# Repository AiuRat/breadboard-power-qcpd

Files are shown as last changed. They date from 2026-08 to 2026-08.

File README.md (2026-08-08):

<p align="center">
  <b>Русский</b> | <a href="README.en.md">English</a> | <a href="README.de.md">Deutsch</a>
</p>

# Breadboard Power QC/PD

Модуль комбинированного питания для беспаечных макетных плат с поддержкой протоколов быстрой зарядки **USB Power Delivery (PD)** и **Quick Charge (QC)**.

<p align="center">
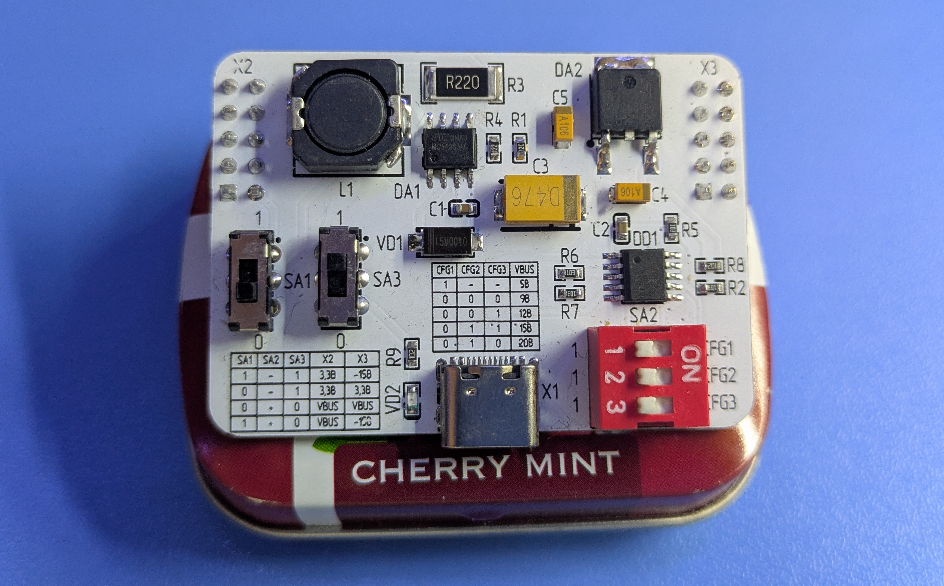
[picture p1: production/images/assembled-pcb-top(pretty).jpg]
Breadboard Power QC/PD Assembled Board
  
</p>

---

## 1. Описание проекта

**Breadboard Power QC/PD** — это компактное, универсальное устройство, призванное решить проблему питания прототипов на беспаечных макетных платах. Традиционные лабораторные блоки питания громоздки и требуют ручной настройки, а дешевые китайские модули питания макеток ограничены жесткими рамками 5 В и 3,3 В при малом токе.

Данный проект объединяет современные технологии быстрой зарядки по протоколу **USB Type-C (QC/PD)**, высокую точность линейных стабилизаторов и широкие возможности импульсных DC-DC преобразователей. Модуль подключается напрямую в боковые шины макетной платы и предоставляет инженеру независимые каналы питания для цифровой логики, микроконтроллеров и аналоговых микросхем (двуполярное питание ±15 В).

---

## 2. Основные технические характеристики

* **Входной интерфейс:** USB Type-C (с поддержкой PD 3.0 / QC 3.0)
* **Интерфейс подключения:** Двухрядные штыревые разъемы с шагом 2,54 мм (под стандартные шины макетных плат)
* **Доступные каналы и напряжения:**
  * Силовой регулируемый канал (`VBUS`): **5 В / 9 В / 12 В / 15 В / 20 В** (определяется триггером)
  * Канал питания логики (`3.3Vout`): **+3,3 В** (малошумящий линейный LDO-стабилизатор)
  * Канал отрицательного плеча (`-15out`): **-15 В** (импульсный инвертирующий преобразователь)

---

## 3. Схемотехника и архитектура устройства

Полная принципиальная электрическая схема модуля:

<p align="center">
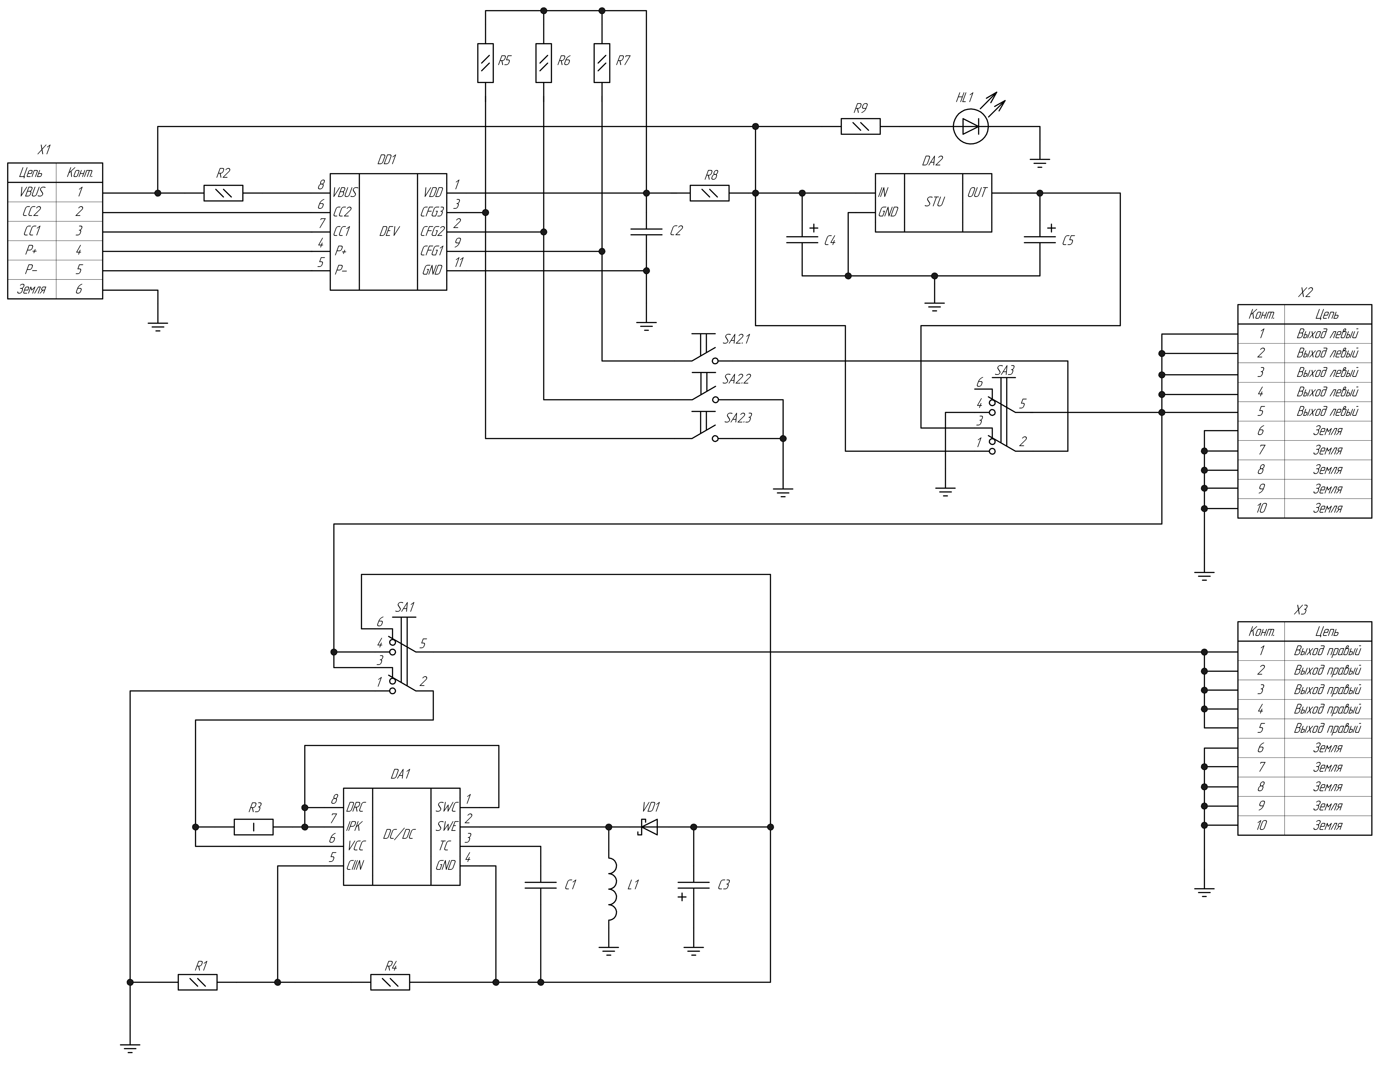
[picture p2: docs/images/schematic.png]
Принципиальная схема Breadboard Power QC/PD
  
</p>

### Архитектура модуля состоит из трех ключевых узлов:
1. **Узел триггера быстрой зарядки:** Выполнен на специализированной микросхеме **CH224K**. Она ведет переговоры с внешним источником питания (адаптером) через линии `CC1/CC2` и «вытягивает» нужное напряжение на шину `VBUS`. Конфигурация задается DIP-переключателем `SA2`.
2. **Линейный LDO-стабилизатор (+3,3 В):** Построен на базе микросхемы **LD1086DT33TR** (в корпусе TO-252) с входными и выходными фильтрующими конденсаторами емкостью 10 мкФ.
3. **Импульсный инвертор (-15 В):** Выполнен по инвертирующей схеме на ШИМ-контроллере **MC34063AG-S08-R** без внешнего ключа. Частота работы генератора задается емкостью $C_1 = 2{,}2\text{ нФ}$ ($\approx 97{,}5\text{ кГц}$).

---

## 4. Конструкция и 3D-моделирование (Mechanical Design)

Для защиты электроники и удобства использования был спроектирован двухсоставной защитный пластиковый корпус в среде **КОМПАС-3D** (соединение деталей по системе шип-паз):

<p align="center">
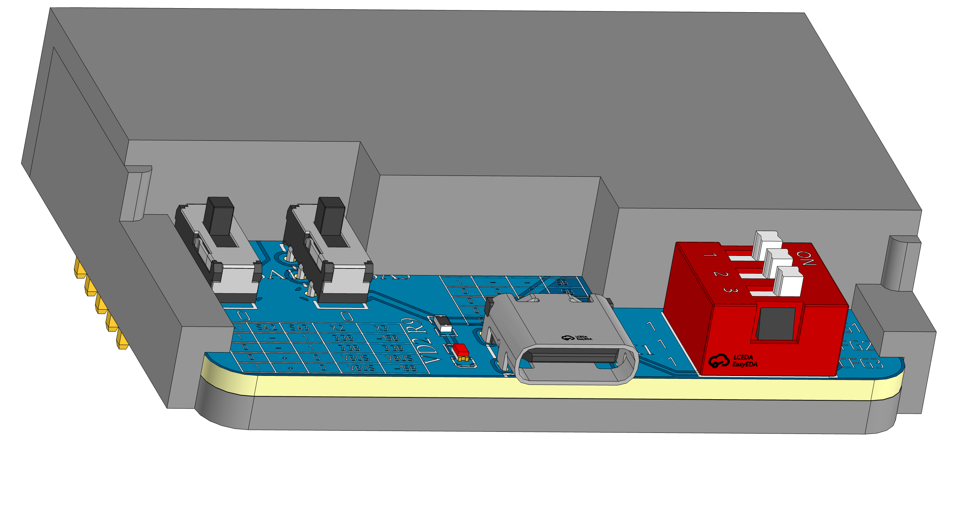
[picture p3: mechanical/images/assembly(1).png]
3D-модель корпуса - Вид 1
  
</p>

*Детали корпуса (крышка и подложка) оптимизированы под аддитивное производство методом FDM-печати на 3D-принтере (файлы `.stl` для печати находятся в папке [`mechanical/enclosure/`](mechanical/enclosure)).*

---

## 5. Лабораторные испытания и верификация (Hardware Verification)

Устройство было успешно спаяно и прошло тестирование:

<p align="center">
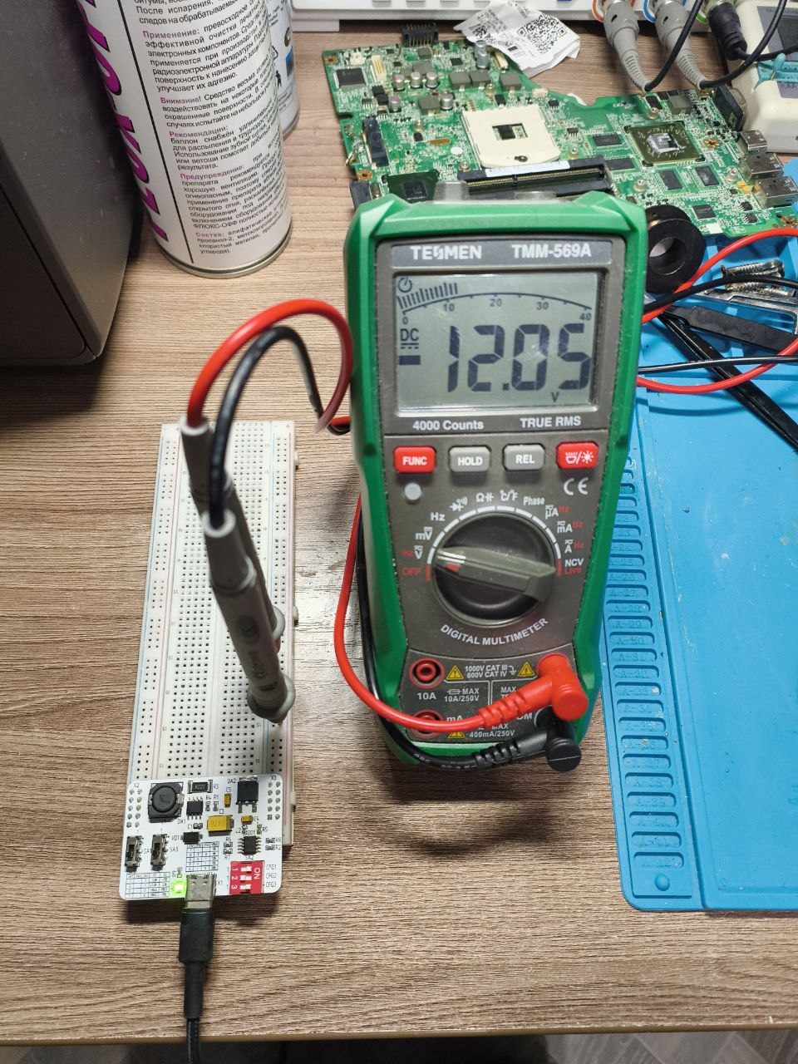
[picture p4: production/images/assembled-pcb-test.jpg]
Физическое тестирование собранного макета
  
</p>

В ходе верификации с помощью цифрового осциллографа была подтверждена стабильность работы встроенного генератора инвертора и непрерывный режим работы силовой индуктивности:

<p align="center">
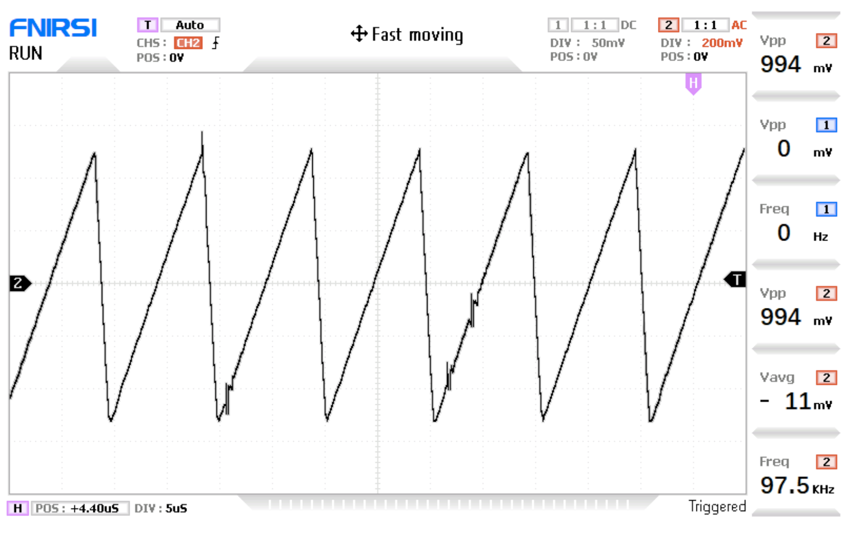
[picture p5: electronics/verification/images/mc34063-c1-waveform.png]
Осциллограмма C1
  
  &nbsp;&nbsp;&nbsp;&nbsp;
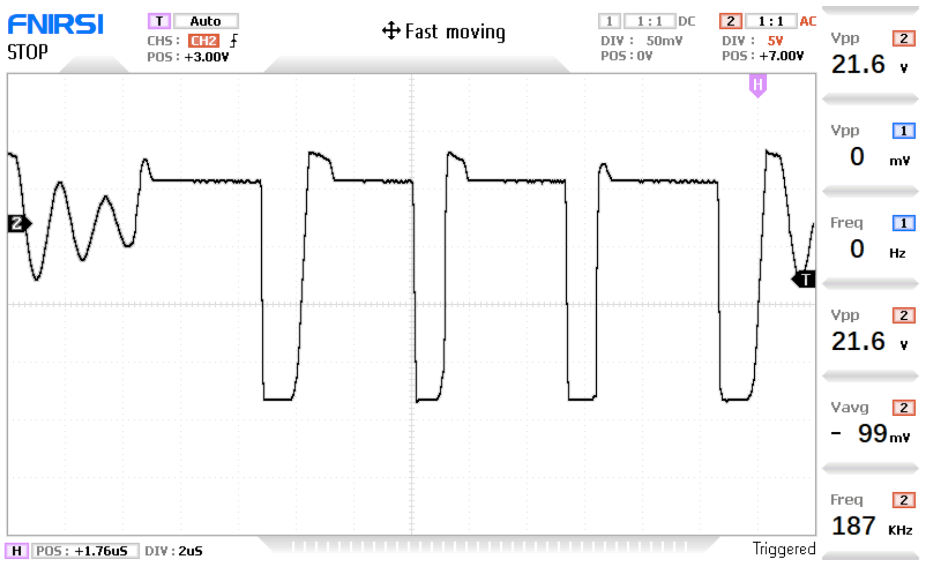
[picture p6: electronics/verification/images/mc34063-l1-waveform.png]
Осциллограмма L1
  
</p>

* **Осциллограмма C1 (слева):** Подтверждает рабочую частоту переключения преобразователя 97,5 кГц (в пределах допустимой нормы в 100 кГц).
* **Осциллограмма L1 (справа):** Подтверждает правильный выбор индуктивности 220 мкГн, обеспечивающий стабильный непрерывный ток дросселя без ухода в режим разрывных токов.

---

## 6. Таблицы конфигурации переключателей

### 6.1. Выбор входного напряжения QC/PD (Переключатель `SA2`)

| `CFG1` | `CFG2` | `CFG3` | Выходное напряжение `VBUS` |
| :---: | :---: | :---: | :---: |
| 1 | — | — | **5 В** |
| 0 | 0 | 0 | **9 В** |
| 0 | 0 | 1 | **12 В** |
| 0 | 1 | 1 | **15 В** |
| 0 | 1 | 0 | **20 В** |

*Примечание: «1» означает разомкнутое состояние переключателя (высокий уровень за счет подтяжки к VDD), «0» — замкнут на GND.*

### 6.2. Коммутация шин питания макетной платы (Переключатели `SA1`, `SA3`)

| Положение `SA1` | Положение `SA3` | Напряжение на левой шине `X2` | Напряжение на правой шине `X3` |
| :---: | :---: | :---: | :---: |
| 1 | 1 | +3,3 В | -15 В |
| 0 | 1 | +3,3 В | +3,3 В |
| 0 | 0 | `VBUS` (от триггера) | `VBUS` (от триггера) |
| 1 | 0 | `VBUS` (от триггера) | -15 В |

---

## 7. Навигация по проекту

Репозиторий имеет четкую модульную структуру. Перейдите в интересующий вас раздел по ссылкам ниже для ознакомления с исходными материалами:

* 📁 **[`/electronics`](electronics)** — Аппаратная часть проекта. Содержит исходные файлы схемы и платы в формате EasyEDA, а также подпапку **[`verification`](electronics/verification)** с подробными математическими расчетами обвязки преобразователя и осциллограммами тестов.
* 📁 **[`/mechanical`](mechanical)** — Механическая часть и корпус. Содержит исходные параметрические модели деталей корпуса в КОМПАС-3D (`.m3d`, `.a3d`) и готовые файлы для 3D-печати на FDM-принтере (`.stl`).
* 📁 **[`/production`](production)** — Файлы для самостоятельной сборки и заказа. Содержит архив Gerber-файлов для завода (`gerber.zip`), перечень элементов для закупки компонентов (`BOM.xlsx`) и чертежи в формате PDF.
* 📁 **[`/docs`](docs)** — Техническая документация. Содержит глубокое описание физики работы схемы устройства, таблицы истинности переключателей и подпапку **[`datasheets`](docs/datasheets)** с оригинальной документацией на используемые микросхемы.

---

## Лицензия

Copyright (c) 2026 Айрат Ялалетдинов

Этот исходный документ описывает открытое аппаратное обеспечение (Open Hardware) и распространяется под лицензией CERN-OHL-P v2. 
Вы можете распространять и изменять этот исходный документ, а также производить на его основе продукты в соответствии с 
условиями лицензии CERN-OHL-P v2 (https://cern.ch/cern-ohl).

Этот исходный документ распространяется БЕЗ КАКИХ-ЛИБО ЯВНЫХ ИЛИ ПОДРАЗУМЕВАЕМЫХ ГАРАНТИЙ, 
ВКЛЮЧАЯ ГАРАНТИИ ТОВАРНОЙ ПРИГОДНОСТИ, УДОВЛЕТВОРИТЕЛЬНОГО КАЧЕСТВА ИЛИ СООТВЕТСТВИЯ 
КОНКРЕТНЫМ ЦЕЛЯМ. Пожалуйста, ознакомьтесь с условиями CERN-OHL-P v2 для получения подробной информации.

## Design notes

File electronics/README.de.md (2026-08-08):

<p align="center">
  <a href="README.md">Русский</a> | <a href="README.en.md">English</a> | <b>Deutsch</b>
</p>

# Hardware-Entwicklung (Electronics)

Hier befinden sich alle Materialien im Zusammenhang mit dem Entwurf, der Berechnung und dem Layout der Leiterplatte des kombinierten Stromversorgungsmoduls.

## Verzeichnisstruktur

* **[`easyeda`](/electronics/easyeda)** — Original-Projektdateien im `.json`-Format für den Import in EasyEDA CAD (Schaltplan und Leiterplatten-Topologie).
* **[`verification`](/electronics/verification)** — Ordner mit detaillierten technischen Berechnungen der Bauteildimensionierung, Formeln und Oszillogrammen der physischen Tests des fertigen Prototyps.
* **[`images`](/electronics/images)** — grafische Materialien des Projekts (Screenshots des Schaltplans, der Routing-Ebenen und der 3D-Modelle der Leiterplatte).

---

## Schaltplan des Geräts

Vollständiger elektrischer Schaltplan des Moduls, erstellt in EasyEDA:

<p align="center">
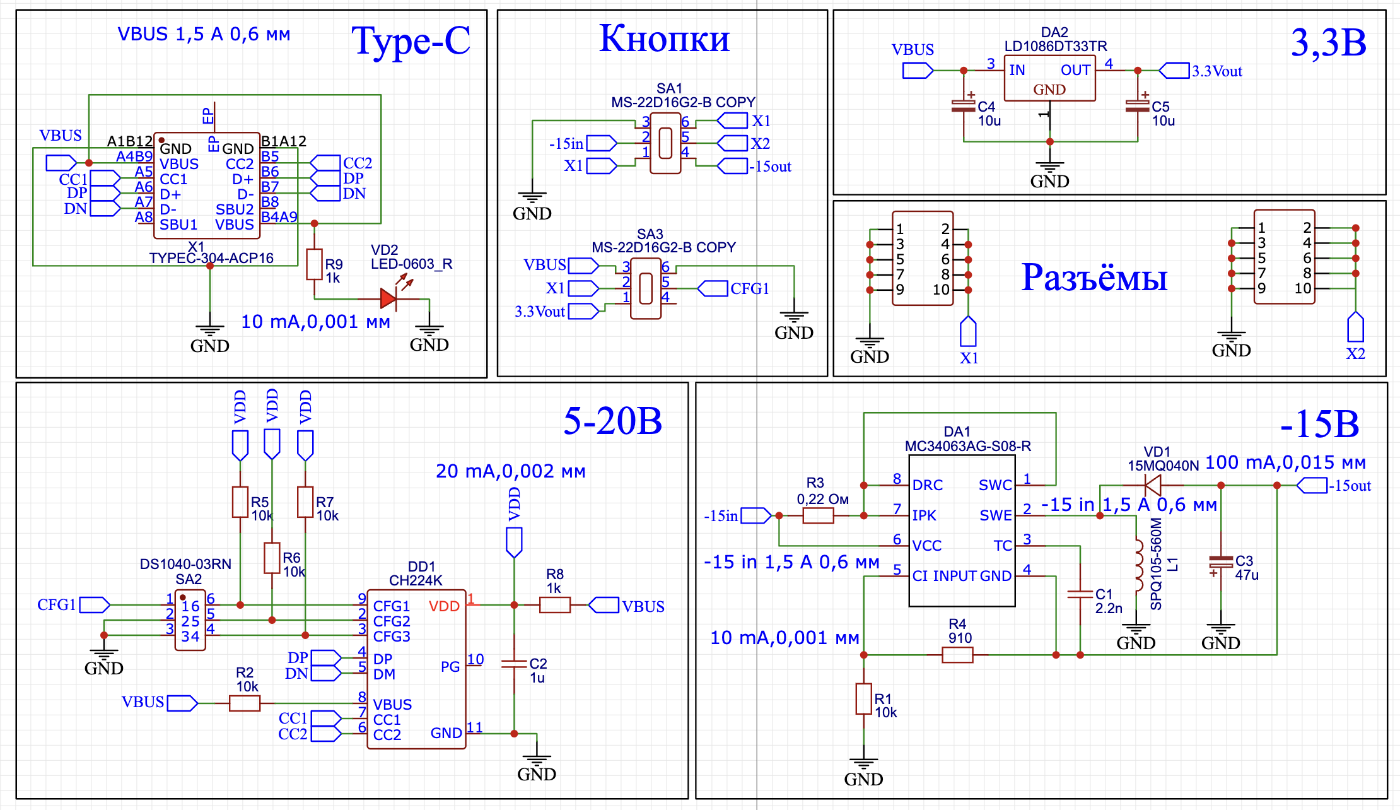
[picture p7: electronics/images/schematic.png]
Schaltplan des Geräts
  
</p>

---

## Leiterplatten-Topologie (PCB)

Zweilagige Leiterplatte mit optimiertem Routing der Leistungsbahnen und Masseflächen (ohne Bauteildarstellung):

<p align="center">
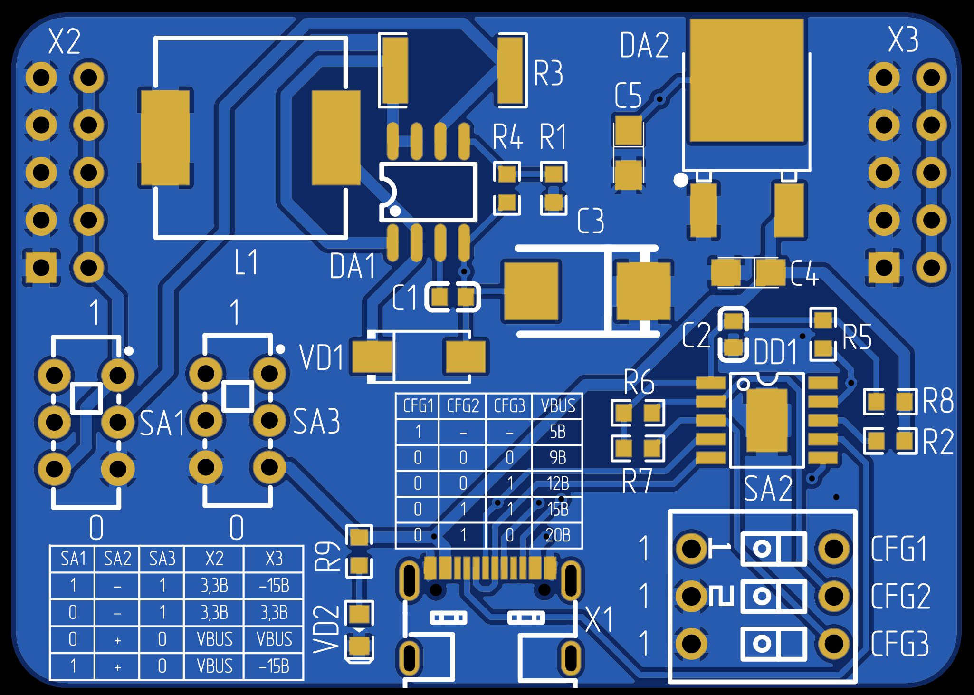
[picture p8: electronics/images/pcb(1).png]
Leiterplatten-Topologie - Draufsicht
  
  &nbsp;&nbsp;&nbsp;&nbsp;
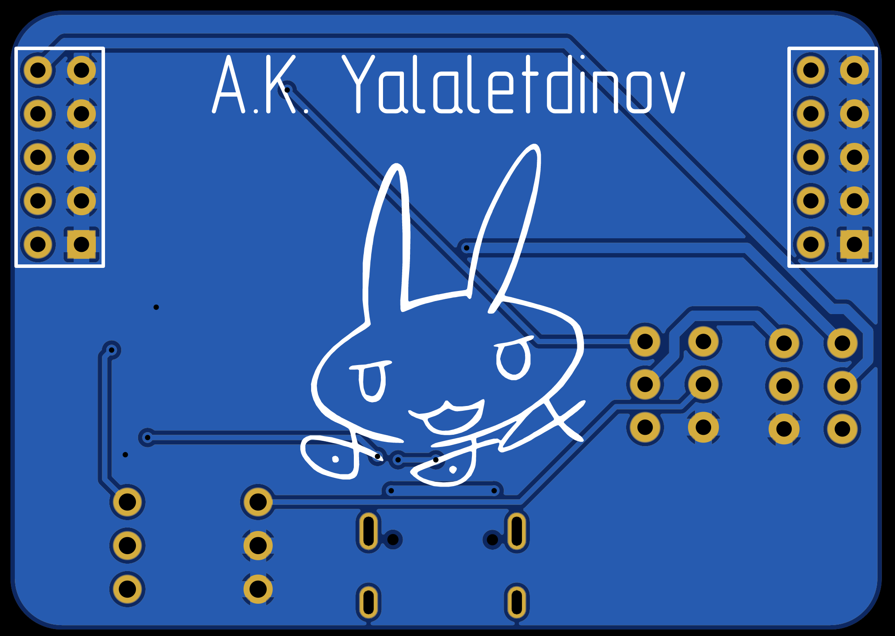
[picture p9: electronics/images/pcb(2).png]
Leiterplatten-Topologie - Unteransicht
  
</p>

---

## 3D-Visualisierung (3D Render)

Realistische 3D-Renderings der Leiterplatte mit bestückten Bauteilen:

<p align="center">
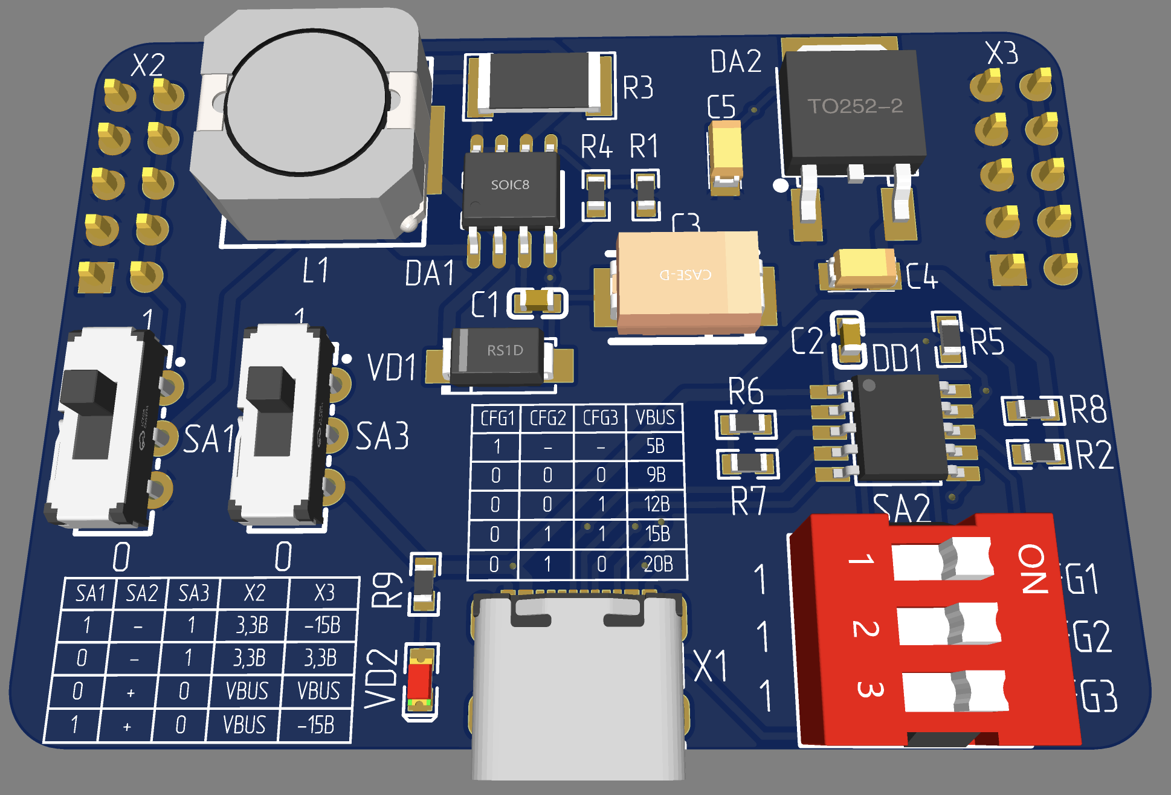
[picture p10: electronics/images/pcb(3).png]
3D-Modell der Leiterplatte - Ansicht 1
  
  &nbsp;&nbsp;&nbsp;&nbsp;
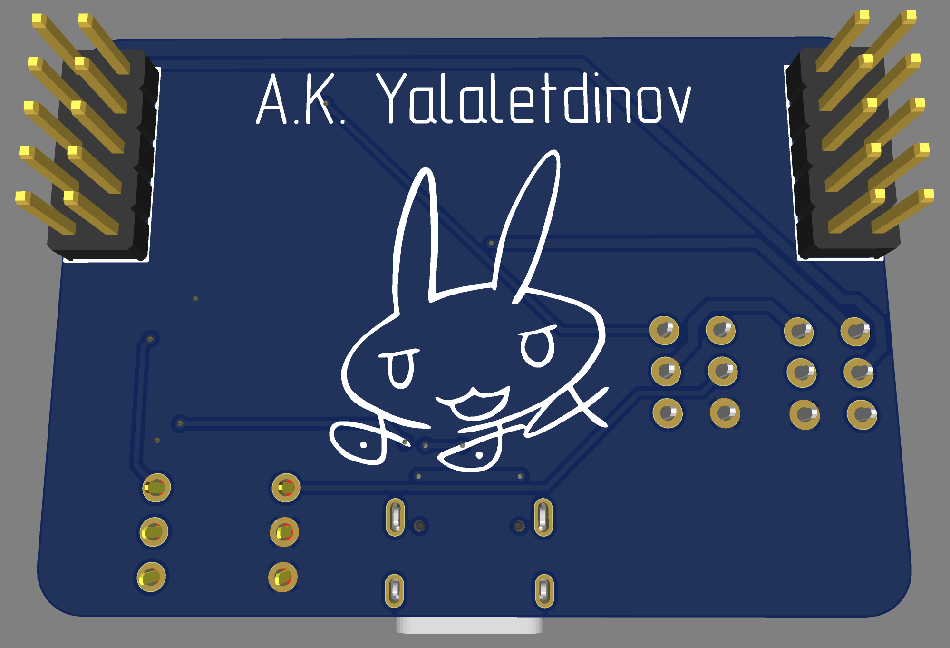
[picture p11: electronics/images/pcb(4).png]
3D-Modell der Leiterplatte - Ansicht 2
  
</p>

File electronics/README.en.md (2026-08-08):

<p align="center">
  <a href="README.md">Русский</a> | <b>English</b> | <a href="README.de.md">Deutsch</a>
</p>

# Hardware Development (Electronics)

This folder contains all materials related to the design, calculation, and routing of the combined power module PCB.

## Directory Structure

* **[`easyeda`](/electronics/easyeda)** — source project files in `.json` format for import into EasyEDA CAD (schematic and PCB topology).
* **[`verification`](/electronics/verification)** — folder with detailed engineering calculations for component values, formulas, and waveforms from physical testing of the finished prototype.
* **[`images`](/electronics/images)** — graphical assets of the project (screenshots of the schematic, routing layers, and 3D PCB models).

---

## Device Schematic Diagram

Full electrical schematic diagram of the module, designed in EasyEDA:

<p align="center">
  Device schematic diagram
</p>

---

## PCB Topology

Two-layer printed circuit board with optimized routing of power traces and ground planes (components not shown):

<p align="center">
  PCB topology - top view
  &nbsp;&nbsp;&nbsp;&nbsp;
  PCB topology - bottom view
</p>

---

## 3D Visualization (3D Render)

Realistic 3D renders of the printed circuit board with installed components:

<p align="center">
  3D PCB model - angle 1
  &nbsp;&nbsp;&nbsp;&nbsp;
  3D PCB model - angle 2
</p>

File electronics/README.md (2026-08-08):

<p align="center">
  <b>Русский</b> | <a href="README.en.md">English</a> | <a href="README.de.md">Deutsch</a>
</p>

# Разработка аппаратной части (Electronics)

Здесь содержатся все материалы, связанные с проектированием, расчетом и трассировкой печатной платы модуля комбинированного питания.

## Структура директории

* **[`easyeda`](/electronics/easyeda)** — исходные файлы проекта в формате `.json` для импорта в САПР EasyEDA (принципиальная схема и топология печатной платы).
* **[`verification`](/electronics/verification)** — папка с подробными инженерными расчетами обвязки микросхем, формулами и осциллограммами физических испытаний готового макета.
* **[`images`](/electronics/images)** — графические материалы проекта (скриншоты схемы, слоев трассировки и 3D-модели платы).

---

## Принципиальная схема устройства

Полная принципиальная электрическая схема модуля, выполненная в EasyEDA:

<p align="center">
  Принципиальная схема устройства
</p>

---

## Топология печатной платы (PCB)

Двухслойная печатная плата с оптимизированной разводкой силовых дорожек и полигонов заземления (без отображения компонентов):

<p align="center">
  Топология платы - вид сверху
  &nbsp;&nbsp;&nbsp;&nbsp;
  Топология платы - вид снизу
</p>

---

## Трехмерная визуализация (3D Render)

Реалистичные 3D-рендеры печатной платы с установленной элементной базой:

<p align="center">
  3D модель платы - ракурс 1
  &nbsp;&nbsp;&nbsp;&nbsp;
  3D модель платы - ракурс 2
</p>

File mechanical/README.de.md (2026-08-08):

<p align="center">
  <a href="README.md">Русский</a> | <a href="README.en.md">English</a> | <b>Deutsch</b>
</p>

# Mechanische Konstruktion (Mechanical)

Hier befinden sich alle Materialien im Zusammenhang mit der Konstruktion, der 3D-Gehäusemodellierung und der Erstellung der Konstruktionsdokumentation.

## Verzeichnisstruktur

* **[`drawings/`](/mechanical/drawings)** — Ordner mit Konstruktionszeichnungen und Spezifikationen im Originalformat von KOMPAS-3D (`.cdw`).
* **[`enclosure/`](/mechanical/enclosure)** — parametrische 3D-Modelle der Gehäuseteile (`.m3d`), fertige 3D-Druckdateien (`.stl`) und das 3D-Modell des montierten Geräts (`.a3d`).
* **[`images/`](/mechanical/images)** — grafische Materialien (hochwertige Renders von 3D-Modellen und Screenshots von Zeichnungen).

---

## 3D-Gehäusebaugruppe (3D Enclosure Assembly)

Renderings des in KOMPAS-3D entworfenen 3D-Gehäusemodells (Abdeckung und Bodenplatte) zusammen mit der Leiterplatte:

<p align="center">
  Gehäusebaugruppe - Ansicht 1
  &nbsp;&nbsp;&nbsp;&nbsp;
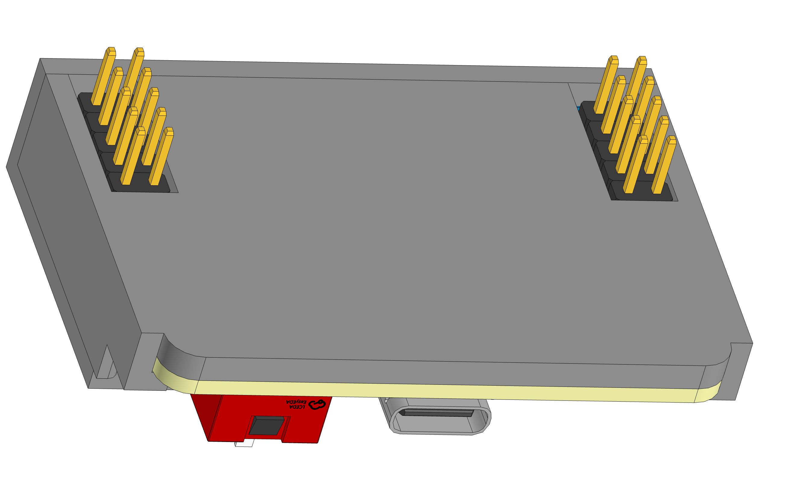
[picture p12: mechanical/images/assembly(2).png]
Gehäusebaugruppe - Ansicht 2
  
</p>

---

## Konstruktionszeichnungen des Produkts (Drawings)

Nachfolgend sind die wichtigsten Blätter der grafischen Dokumentation des Projekts dargestellt, die nach ESKD-Standards erstellt wurden:

### 1. Elektrischer Schaltplan (Schematic)
<p align="center">
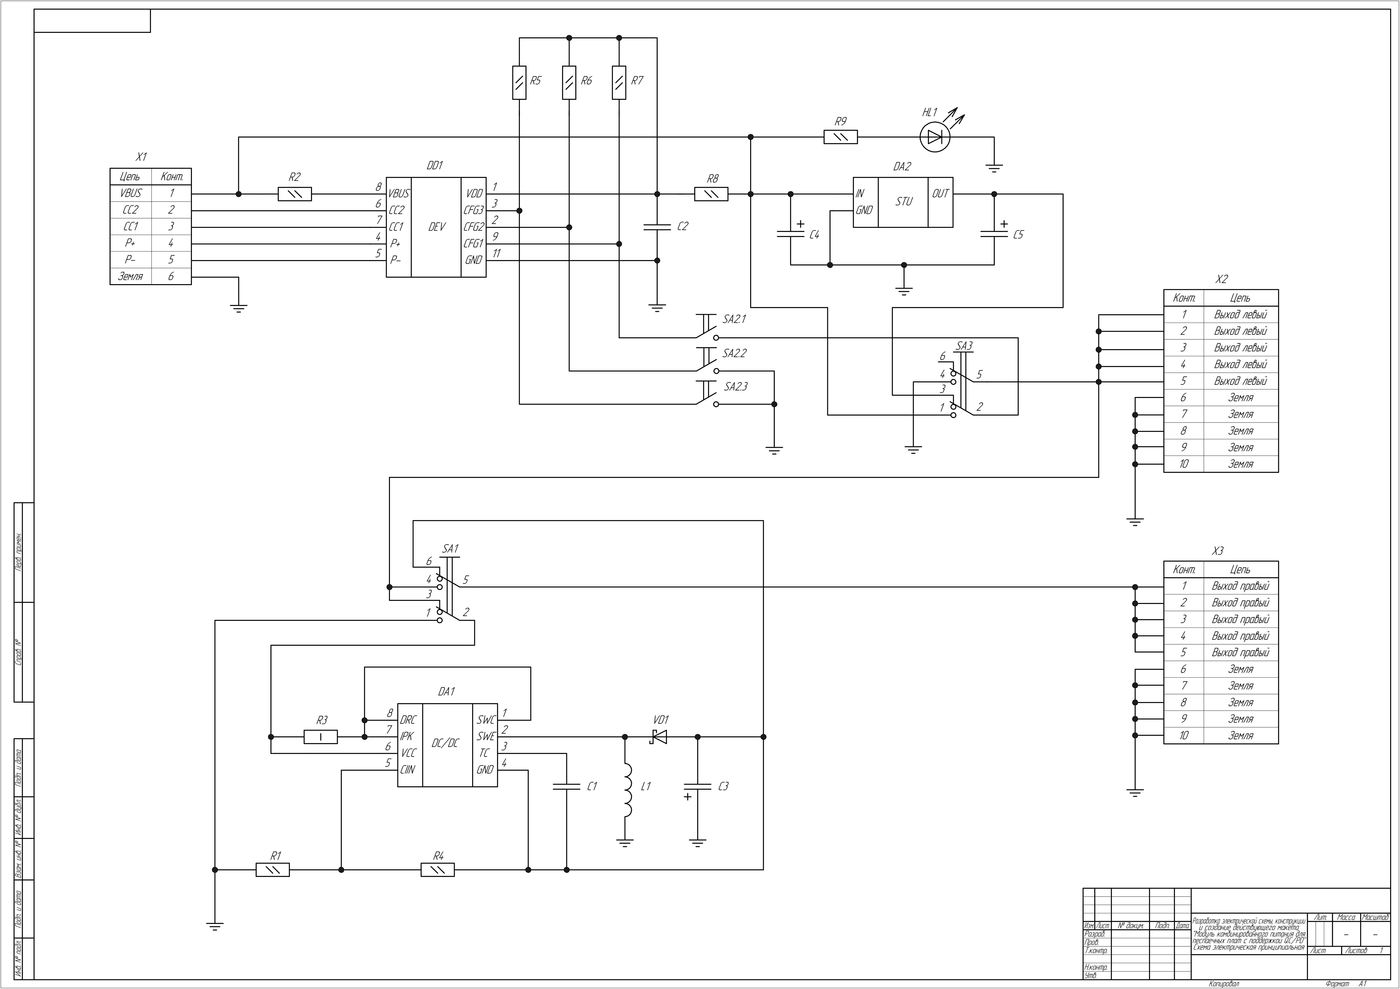
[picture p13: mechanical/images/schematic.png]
Elektrischer Schaltplan
  
</p>

### 2. Baugruppenzeichnung des Geräts (Assembly Drawing)
<p align="center">
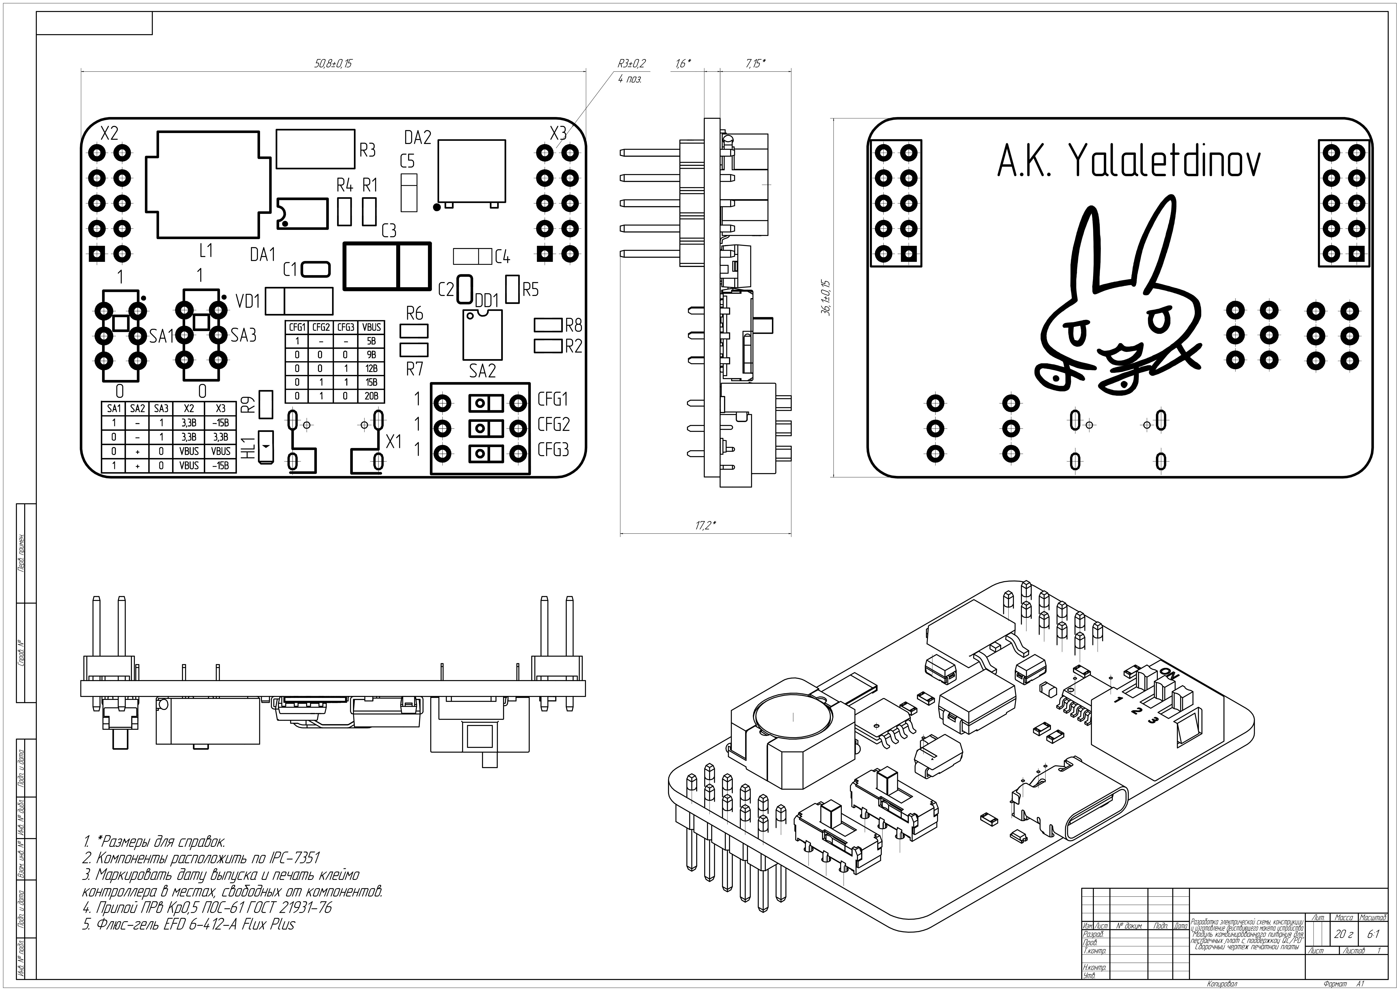
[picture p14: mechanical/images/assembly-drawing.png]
Baugruppenzeichnung des Geräts
  
</p>

### 3. Leiterplattenzeichnung (PCB Drawing)
<p align="center">
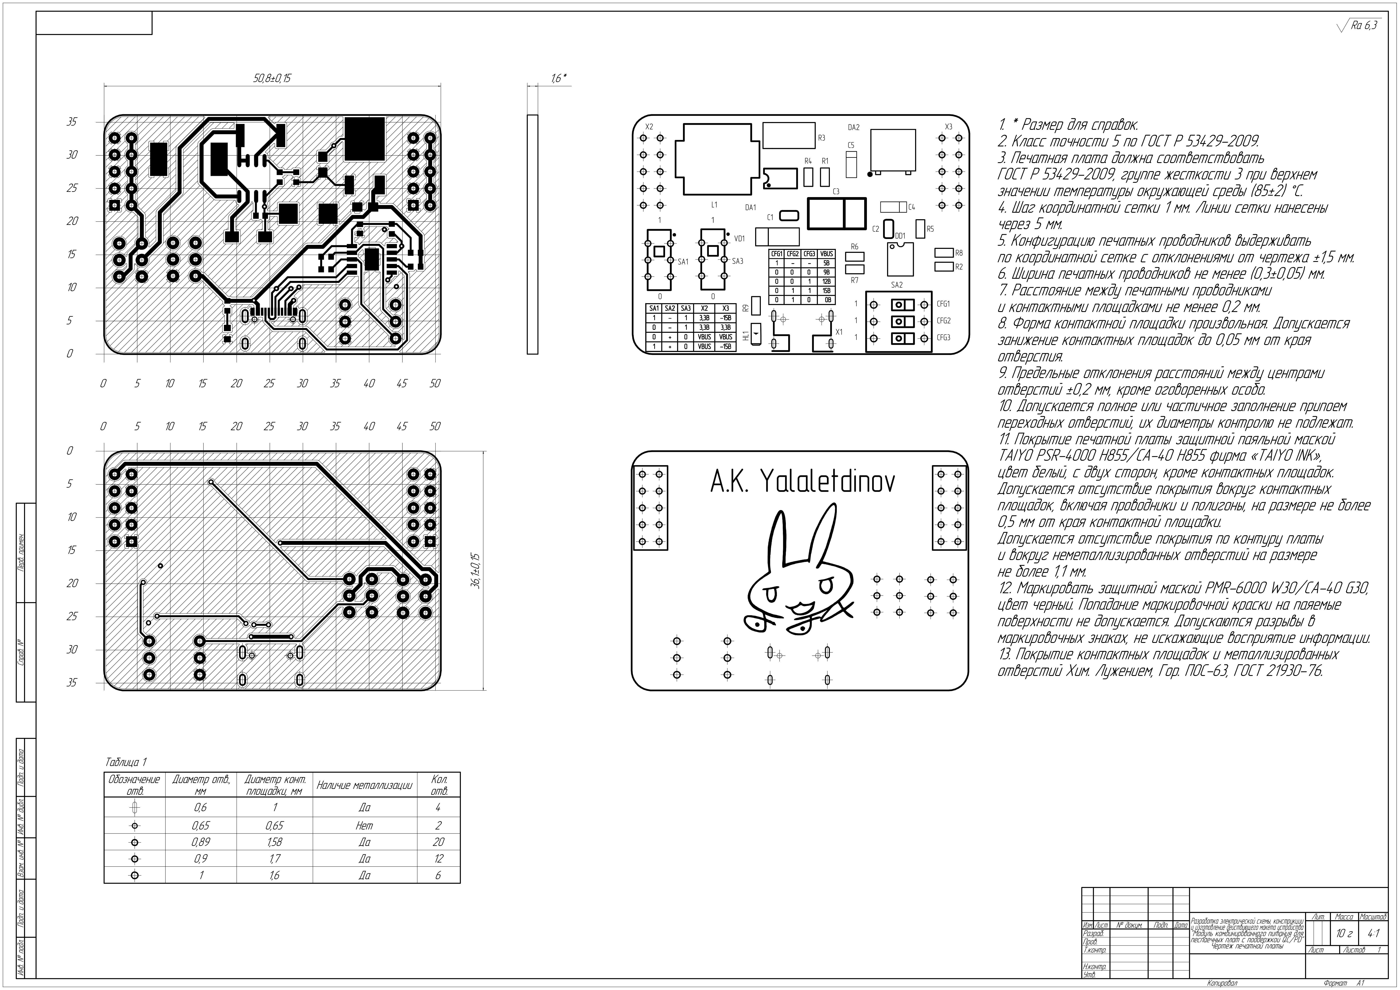
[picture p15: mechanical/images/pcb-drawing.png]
Leiterplattenzeichnung
  
</p>

### 4. Gesamtansichtszeichnung des Produkts (General View)
<p align="center">
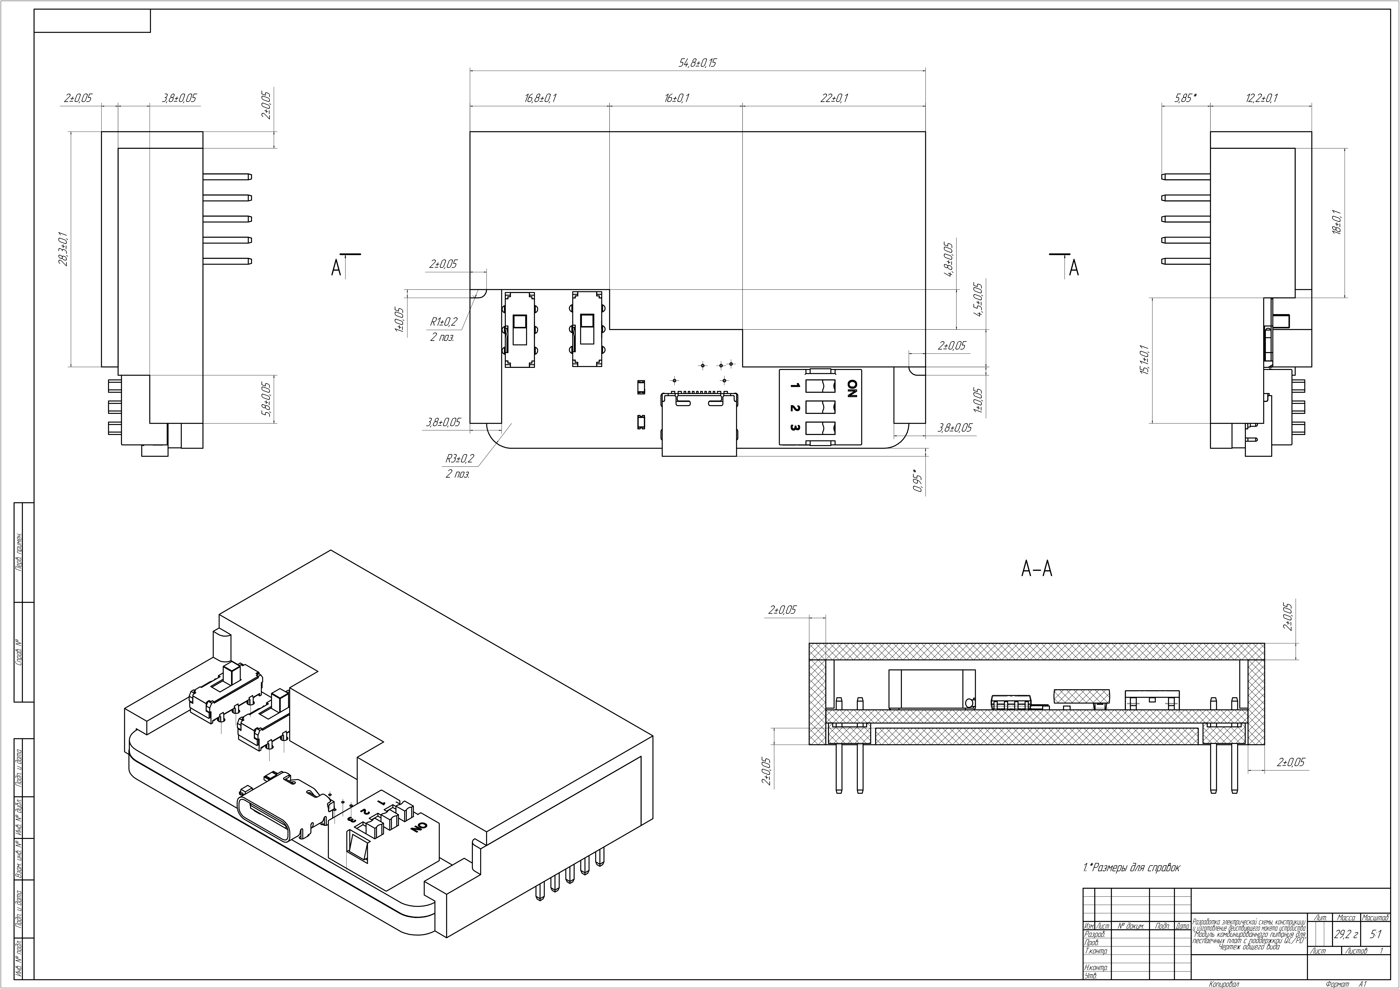
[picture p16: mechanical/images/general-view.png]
Gesamtansichtszeichnung des Produkts
  
</p>

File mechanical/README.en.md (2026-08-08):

<p align="center">
  <a href="README.md">Русский</a> | <b>English</b> | <a href="README.de.md">Deutsch</a>
</p>

# Mechanical Design (Mechanical)

This folder contains all materials related to structural development, 3D enclosure modeling, and engineering documentation release.

## Directory Structure

* **[`drawings/`](/mechanical/drawings)** — folder with engineering drawings and specifications in the native KOMPAS-3D format (`.cdw`).
* **[`enclosure/`](/mechanical/enclosure)** — parametric 3D models of enclosure parts (`.m3d`), ready-to-print 3D printing files (`.stl`), and the 3D model of the assembled device (`.a3d`).
* **[`images/`](/mechanical/images)** — graphical assets (high-quality 3D model renders and drawing screenshots).

---

## 3D Enclosure Assembly

Renders of the 3D enclosure model (top cover and bottom plate) assembled with the printed circuit board, designed in KOMPAS-3D:

<p align="center">
  Enclosure Assembly - Angle 1
  &nbsp;&nbsp;&nbsp;&nbsp;
  Enclosure Assembly - Angle 2
</p>

---

## Engineering Drawings

Below are the main sheets of the project's graphical documentation, prepared in accordance with ESKD standards:

### 1. Electrical Schematic Diagram (Schematic)
<p align="center">
  Electrical Schematic Diagram
</p>

### 2. Device Assembly Drawing (Assembly Drawing)
<p align="center">
  Device Assembly Drawing
</p>

### 3. Printed Circuit Board Drawing (PCB Drawing)
<p align="center">
  Printed Circuit Board Drawing
</p>

### 4. General View Drawing (General View)
<p align="center">
  General View Drawing
</p>

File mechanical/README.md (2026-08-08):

<p align="center">
  <b>Русский</b> | <a href="README.en.md">English</a> | <a href="README.de.md">Deutsch</a>
</p>

# Проектирование механической части (Mechanical)

Здесь содержатся все материалы, связанные с разработкой конструкции, 3D-моделированием корпуса и выпуском конструкторской документации.

## Структура директории

* **[`drawings/`](/mechanical/drawings)** — папка с конструкторскими чертежами и спецификациями в исходном формате КОМПАС-3D (`.cdw`).
* **[`enclosure/`](/mechanical/enclosure)** — параметрические 3D-модели деталей корпуса по частям (`.m3d`), готовые файлы для 3D-печати (`.stl`) и 3D-модель устройства в сборе (`.a3d`).
* **[`images/`](/mechanical/images)** — графические материалы (высококачественные рендеры 3D-моделей и скриншоты чертежей).

---

## Трехмерная сборка корпуса (3D Enclosure Assembly)

Рендеры 3D-модели корпуса (крышка и подложка) в сборе с печатной платой, спроектированные в среде КОМПАС-3D:

<p align="center">
  Сборка корпуса - Ракурс 1
  &nbsp;&nbsp;&nbsp;&nbsp;
  Сборка корпуса - Ракурс 2
</p>

---

## Конструкторские чертежи изделия (Drawings)

Ниже представлены основные листы графической документации проекта, выполненные по стандартам ЕСКД:

### 1. Схема электрическая принципиальная (Schematic)
<p align="center">
  Схема электрическая принципиальная
</p>

### 2. Сборочный чертеж устройства (Assembly Drawing)
<p align="center">
  Сборочный чертеж устройства
</p>

### 3. Чертеж печатной платы (PCB Drawing)
<p align="center">
  Чертеж печатной платы
</p>

### 4. Чертеж общего вида изделия (General View)
<p align="center">
  Чертеж общего вида изделия
</p>

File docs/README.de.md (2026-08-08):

<p align="center">
  <a href="README.md">Русский</a> | <a href="README.en.md">English</a> | <b>Deutsch</b>
</p>

# Funktionsbeschreibung des Schaltungsentwurfs des kombinierten Stromversorgungsmoduls

Dieses Dokument enthält eine detaillierte technische Beschreibung der Funktionsweise des elektrischen Schaltplans für das "Kombinierte Stromversorgungsmodul für lötfreie Steckplatinen (Breadboards) mit QC/PD-Unterstützung".

<p align="center">
  Schaltplan des Geräts
</p>

## 1. Verwendungszweck und Gesamtarchitektur

Das Gerät ist dafür ausgelegt, lötfreie Steckplatinen während des Prototyping und des Debugging von elektronischen Geräten mit einer stabilen mehrkanaligen Stromversorgung zu versorgen. Das Modul wandelt die Eingangsspannung eines externen Ladegeräts oder einer externen Powerbank, die Schnellladeprotokolle unterstützen, in einen Satz stabilisierter Spannungen um:
* **Schnellladekanal (VBUS):** einstellbare Spannung von $5\text{ V}$, $9\text{ V}$, $12\text{ V}$, $15\text{ V}$ oder $20\text{ V}$ (wird durch die Trigger-Anforderung bestimmt).
* **Niederspannungskanal für Logikversorgung:** feste Spannung von $+3{,}3\text{ V}$.
* **Negativer Spannungskanal (symmetrische Spannungsversorgung):** feste Spannung von $-15\text{ V}$.

---

## 2. Funktionsweise der einzelnen Baugruppen

Der elektrische Schaltplan des Geräts besteht aus fünf miteinander verbundenen Hauptblöcken:

### 2.1. USB Type-C Eingangsstufe
Der Betrieb des Moduls beginnt mit dem Anlegen einer externen Stromversorgung an den Anschluss **`X1`** (Typ *TYPEC-304-ACP16*). 
* Die Kontakte `A4/B9` und `B4/A9` sind zu einer gemeinsamen Eingangsstromschiene **`VBUS`** zusammengefasst.
* Die Kontakte `A1/B12` und `B1/A12` sind mit der Systemmasse **`GND`** verbunden.
* Die Kanalkonfigurationskontakte `CC1` und `CC2` sind zum Schnelllade-Trigger herausgeführt, um die Aushandlung mit der Stromquelle durchzuführen.
* Die LED **`VD2`** (mit dem Strombegrenzungswiderstand `R10` von $1\text{ k}\Omega$) dient zur visuellen Anzeige der Eingangsspannung auf der `VBUS`-Schiene.

### 2.2. Aushandlungseinheit für Schnellladeprotokolle (QC/PD)
Das Schlüsselelement für die Kommunikation mit dem Netzteil ist der Trigger-IC **`DD1`** vom Typ **`CH224K`**. Er unterstützt hardwareseitig die Protokolle USB Power Delivery (PD3.0/2.0), Quick Charge (QC3.0/2.0) und andere.
* Die Signalleitungen `DP` (D+) und `DM` (D-) sowie die Konfigurationsleitungen `CC1` und `CC2` sind direkt mit den entsprechenden Pins von `DD1` verbunden.
* Die Betriebslogik des Triggers wird durch den Zustand seiner Konfigurationseingänge `CFG1`, `CFG2` und `CFG3` bestimmt. Diese Eingänge werden durch die Widerstände `R5`, `R6`, `R7` von $10\text{ k}\Omega$ auf die interne Versorgungsschiene `VDD` hochgezogen (pull-up) und über einen dreistufigen DIP-Schalter **`SA2`** (*DS1040-03RN*) gesteuert.
* Durch Schließen der entsprechenden Kontakte des Schalters `SA2` gegen Masse (`GND`) stellt der Benutzer manuell den gewünschten Spannungspegel (von $5\text{ V}$ bis $20\text{ V}$) ein.

### 2.3. LDO-Linearreglerstufe ($+3{,}3\text{ V}$)
Für die zuverlässige Stromversorgung von Mikrocontrollern und digitalen Sensoren wird ein leistungsstarker Linearregler mit geringem Spannungsabfall (LDO) **`DA2`** vom Typ **`LD1086DT33TR`** (im TO-252-Gehäuse) verwendet.
* Die Spannung von der Schiene `VBUS` wird an den Eingang `IN` des Reglers angelegt. Obwohl `VBUS` bis auf $20\text{ V}$ ansteigen kann, hält der IC `LD1086` Eingangsspannungen von bis zu $30\text{ V}$ sicher stand.
* Zur Unterdrückung hochfrequenter Störungen und transienter Vorgänge sind am Ein- und Ausgang des Reglers Keramikkondensatoren **`C4`** ($10\text{ }\mu\text{F}$) und **`C5`** ($10\text{ }\mu\text{F}$) installiert.

### 2.4. Invertierender DC-DC-Wandler ($-15\text{ V}$)
Die negative Spannung wird von einem invertierenden Schaltregler auf Basis des klassischen PWM-Controllers **`DA1`** vom Typ **`MC34063AG-S08-R`** erzeugt.
* **Prinzip der Invertierung:** Wenn der interne Leistungstransistor des ICs eingeschaltet ist, fließt Strom durch die Drossel **`L1`** ($220\text{ }\mu\text{H}$) und speichert Energie in ihrem Magnetfeld. Die Schottky-Diode **`VD1`** (*15MQ040N*) ist in diesem Moment gesperrt. Wenn der Transistor sperrt, versucht die Induktivität, die Stromrichtung beizubehalten, die Selbstinduktions-EMK kehrt ihre Polarität um, die Diode `VD1` leitet und überträgt negative Ladung auf den Ausgangskondensator **`C3`** ($47\text{ }\mu\text{H}$).
* **Überstromschutz:** Der Widerstand **`R3`** ($0{,}22\text{ }\Omega$) zwischen den Pins `DRC/IPK` und dem Stromeingang legt die Schwelle für die Begrenzung des Drossel-Spitzenstroms fest, um eine Beschädigung des Wandlers bei einem Kurzschluss zu verhindern.
* **Rückkopplung (Feedback):** Die Ausgangsspannung wird von einem Komparator über einen Teiler aus den Widerständen **`R4`** ($910\text{ }\Omega$), **`R5`** ($750\text{ }\Omega$) und **`R1`** ($10\text{ k}\Omega$) überwacht, der an den Rückkopplungseingang `CIIN` (Pin 5) angeschlossen ist. Der Kondensator **`C1`** ($2{,}2\text{ nF}$) bestimmt die Schaltfrequenz des PWM-Generators ($\approx 97{,}5\text{ kHz}$).

### 2.5. Ausgangsschaltschema und Ausgangsanschlüsse
Die Verteilung der Spannungen auf die linke und rechte Schiene der Steckplatine erfolgt über zwei unabhängige Schiebeschalter **`SA1`** und **`SA3`** (*MS-22D16G2-B*).
* Die Schalter leiten die physischen Ausgänge der Schienen `3.3Vout`, `VBUS` und `-15out` an die Ausgangsstiftleisten **`X2`** und **`X3`** (Typ *DS1021-2x5*) weiter.
* Die Anschlüsse haben ein Rastermaß von $2{,}54\text{ mm}$ und befinden sich an den Rändern der Leiterplatte, so dass das Modul direkt in die seitlichen Standard-Stromschienen einer lötfreien Steckplatine gesteckt werden kann.

---

## 3. Konfigurationstabellen der Schalter

### 3.1. Auswahl der QC/PD-Eingangsspannung (Schalter `SA2`)

| `CFG1` | `CFG2` | `CFG3` | Ausgangsspannung `VBUS` |
| :---: | :---: | :---: | :---: |
| 1 | — | — | **5 V** |
| 0 | 0 | 0 | **9 V** |
| 0 | 0 | 1 | **12 V** |
| 0 | 1 | 1 | **15 V** |
| 0 | 1 | 0 | **20 V** |

*Hinweis: „1“ bedeutet geöffneter Zustand des Schalters (High-Pegel durch Pull-up-Widerstand gegen VDD), „0“ bedeutet gegen GND geschlossen.*

### 3.2. Umschalten der Steckplatinen-Stromschienen (Schalter `SA1`, `SA3`)

| `SA1`-Stellung | `SA3`-Stellung | Spannung an der linken Schiene `X2` | Spannung an der rechten Schiene `X3` |
| :---: | :---: | :---: | :---: |
| 1 | 1 | +3,3 V | -15 V |
| 0 | 1 | +3,3 V | +3,3 V |
| 0 | 0 | `VBUS` (vom Trigger) | `VBUS` (vom Trigger) |
| 1 | 0 | `VBUS` (vom Trigger) | -15 V |

---

## 4. Technische Referenzdokumentation (Datasheets)

Für eine detaillierte Untersuchung der Funktionsweise der verwendeten integrierten Schaltungen können Sie die Original-Datenblätter der Hersteller im Repository einsehen:

* 📄 **[`ch224k.pdf`](datasheets/ch224k.pdf)** — USB-Schnelllade-Trigger-Controller (WCH).
* 📄 **[`ld1086.pdf`](datasheets/ld1086.pdf)** — Leistungsstarker rauscharmer LDO-Linearregler (STMicroelectronics).
* 📄 **[`mc34063a.pdf`](datasheets/mc34063a.pdf)** — Universeller PWM-Schaltregler-Controller für DC-DC-Wandler (STMicroelectronics).

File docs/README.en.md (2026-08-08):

<p align="center">
  <a href="README.md">Русский</a> | <b>English</b> | <a href="README.de.md">Deutsch</a>
</p>

# Circuit Operation Description of the Combined Power Module

This document contains a detailed technical description of the operation of the electrical schematic for the "Combined power module for solderless breadboards supporting QC/PD".

<p align="center">
  Device Schematic Diagram
</p>

## 1. Purpose and General Architecture

The device is designed to provide stable multi-channel power to solderless breadboards during prototyping and debugging of electronic equipment. The module converts the input voltage from an external charger or an external battery (Power Bank) supporting fast charging protocols into a set of stabilized voltages:
* **Fast charging channel (VBUS):** adjustable voltage of $5\text{ V}$, $9\text{ V}$, $12\text{ V}$, $15\text{ V}$, or $20\text{ V}$ (determined by the trigger request).
* **Low-voltage logic power channel:** fixed voltage of $+3.3\text{ V}$.
* **Negative voltage channel (dual-polarity power supply):** fixed voltage of $-15\text{ V}$.

---

## 2. Principle of Operation of Functional Circuit Blocks

The electrical schematic of the device consists of five main interconnected blocks:

### 2.1. USB Type-C Input Block
Module operation begins with applying external power to the **`X1`** connector (type *TYPEC-304-ACP16*). 
* Contacts `A4/B9` and `B4/A9` are combined into a common input power rail **`VBUS`**.
* Contacts `A1/B12` and `B1/A12` are connected to the system ground **`GND`**.
* Channel configuration contacts `CC1` and `CC2` are routed to the fast charging trigger for negotiations with the power source.
* The LED **`VD2`** (with current-limiting resistor `R10` of $1\text{ k}\Omega$) serves for visual indication of the input voltage presence on the `VBUS` rail.

### 2.2. Fast Charging Protocol Negotiator Block (QC/PD)
The key element communicating with the adapter is the trigger IC **`DD1`** of type **`CH224K`**. It supports hardware protocols for USB Power Delivery (PD3.0/2.0), Quick Charge (QC3.0/2.0), and others.
* Signal lines `DP` (D+) and `DM` (D-), as well as configuration lines `CC1` and `CC2`, are connected directly to the corresponding pins of `DD1`.
* The trigger's operating logic is determined by the state of its configuration inputs `CFG1`, `CFG2`, and `CFG3`. These inputs are pulled up to the internal power rail `VDD` by resistors `R5`, `R6`, `R7` of $10\text{ k}\Omega$ and are controlled by a three-position DIP switch **`SA2`** (*DS1040-03RN*).
* By closing the corresponding contacts of the `SA2` switch to ground (`GND`), the user manually sets the requested voltage level (from $5\text{ V}$ to $20\text{ V}$ dev).

### 2.3. $+3.3\text{ V}$ Linear Regulator Block
For reliable power supply of microcontrollers and digital sensors, a high-power low-dropout (LDO) linear regulator **`DA2`** of type **`LD1086DT33TR`** (TO-252 package) is used.
* Voltage from the `VBUS` rail is supplied to the `IN` input of the regulator. Although `VBUS` can rise up to $20\text{ V}$, the `LD1086` IC safely tolerates input voltages up to $30\text{ V}$ .
* To suppress high-frequency noise and transient processes, ceramic capacitors **`C4`** ($10\text{ }\mu\text{F}$) and **`C5`** ($10\text{ }\mu\text{F}$) are installed at the input and output of the regulator.

### 2.4. $-15\text{ V}$ Inverting DC-DC Converter Block
Negative voltage is generated by a switching buck-boost converter based on the classic PWM controller **`DA1`** of type **`MC34063AG-S08-R`** in an inverting configuration.
* **Principle of inversion:** When the internal power switch transistor of the IC is on, current flows through the inductor **`L1`** ($220\text{ }\mu\text{H}$), storing energy in its magnetic field. The Schottky diode **`VD1`** (*15MQ040N*) is closed at this moment. When the transistor turns off, the inductance tends to maintain the current direction, the self-induction EMF changes polarity, the diode `VD1` opens, and negative charge is transferred to the output capacitor **`C3`** ($47\text{ }\mu\text{F}$).
* **Overcurrent protection:** Resistor **`R3`** ($0.22\text{ }\Omega$) installed between the `DRC/IPK` pins and the power input sets the peak inductor current limit threshold, preventing converter failure during a short circuit.
* **Feedback:** The output voltage is monitored by a comparator through a divider on resistors **`R4`** ($910\text{ }\Omega$), **`R5`** ($750\text{ }\Omega$), and **`R1`** ($10\text{ k}\Omega$), connected to the feedback input `CIIN` (Pin 5). Capacitor **`C1`** ($2.2\text{ nF}$) sets the switching frequency of the PWM generator ($\approx 97.5\text{ kHz}$).

### 2.5. Output Commutation Scheme and Output Connectors
Distribution of voltages to the left and right rails of the breadboard is carried out using two independent slide switches **`SA1` and `SA3`** (*MS-22D16G2-B*).
* The switches route the physical outputs of the `3.3Vout`, `VBUS`, and `-15out` rails to the output header connectors **`X2` and `X3`** (type *DS1021-2x5*).
* The connectors have a $2.54\text{ mm}$ pitch and are located at the edges of the board in such a way that the module plugs directly into the standard side power rails of a solderless breadboard.

---

## 3. Switch Configuration Tables

### 3.1. QC/PD Input Voltage Selection (Switch `SA2`)

| `CFG1` | `CFG2` | `CFG3` | Output Voltage `VBUS` |
| :---: | :---: | :---: | :---: |
| 1 | — | — | **5 V** |
| 0 | 0 | 0 | **9 V** |
| 0 | 0 | 1 | **12 V** |
| 0 | 1 | 1 | **15 V** |
| 0 | 1 | 0 | **20 V** |

*Note: "1" indicates the open state of the switch (high level due to pull-up to VDD), "0" indicates closed to GND.*

### 3.2. Breadboard Power Rail Commutation (Switches `SA1`, `SA3`)

| `SA1` Position | `SA3` Position | Voltage on Left Rail `X2` | Voltage on Right Rail `X3` |
| :---: | :---: | :---: | :---: |
| 1 | 1 | +3.3 V | -15 V |
| 0 | 1 | +3.3 V | +3.3 V |
| 0 | 0 | `VBUS` (from trigger) | `VBUS` (from trigger) |
| 1 | 0 | `VBUS` (from trigger) | -15 V |

---

## 4. Reference Technical Documentation (Datasheets)

For a detailed study of the operation of the integrated circuits used in the circuit, you can review the original manufacturer technical documentation located in the repository:

* 📄 **[`ch224k.pdf`](datasheets/ch224k.pdf)** — fast USB charging protocol trigger controller (WCH).
* 📄 **[`ld1086.pdf`](datasheets/ld1086.pdf)** — high-power low-noise linear LDO voltage regulator (STMicroelectronics).
* 📄 **[`mc34063a.pdf`](datasheets/mc34063a.pdf)** — universal switching PWM controller for DC-DC converters (STMicroelectronics).

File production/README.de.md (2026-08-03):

<p align="center">
  <a href="README.md">Русский</a> | <a href="README.en.md">English</a> | <b>Deutsch</b>
</p>

# Fertigungsdateien (Production)

Hier befinden sich alle Materialien, die für die Eigenherstellung der Leiterplatte, den Einkauf der Komponenten und die Montage des fertigen Geräts erforderlich sind.

## Inhalt des Verzeichnisses

* **[`gerber.zip`](/production/gerber.zip)** — fertiges Archiv mit Gerber-Dateien und Bohrplan. Vollständig bereit für den Upload auf die Websites der Hersteller (JLCPCB, PCBWay usw.).
* **[`breadboard-power-qcpd-bom.xlsx`](/production/breadboard-power-qcpd-bom.xlsx)** — Stückliste (Bill of Materials) mit Bauteilspezifikationen. 
  *(Hinweis: Die Tabelle enthält direkte Kauf-Links für Elektronikbauteile im Online-Shop „Chip und Dip“, einige Links können jedoch im Laufe der Zeit veralten).*
* **[`drawings/`](/production/drawings)** — vollständiger Satz der Konstruktionsdokumentation (Zeichnungen, Spezifikationen) im **`.pdf`**-Format.

---

## Aussehen des fertigen Geräts

Nachfolgend finden Sie Fotos des montierten und getesteten physischen Prototyps:

### 1. Ansicht der bestückten Leiterplatte
<p align="center">
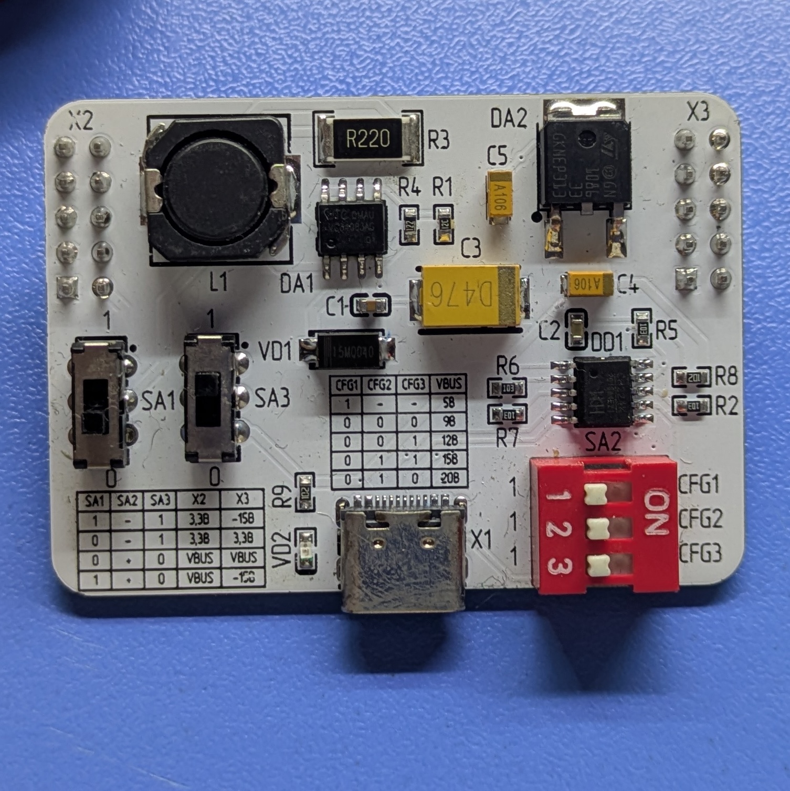
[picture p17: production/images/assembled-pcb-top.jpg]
Modul-Leiterplatte - Draufsicht
  
  &nbsp;&nbsp;&nbsp;&nbsp;
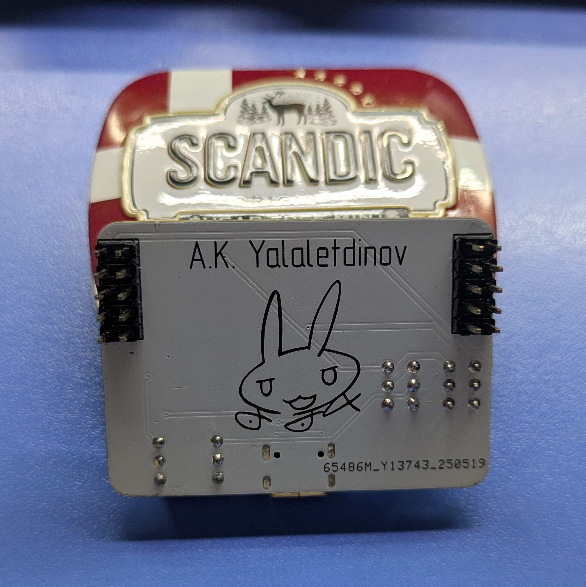
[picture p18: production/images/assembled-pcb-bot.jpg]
Modul-Leiterplatte - Unteransicht
  
</p>

### 2. Labortest des Prototyps
<p align="center">
  Testen des montierten Stromversorgungsmoduls
</p>

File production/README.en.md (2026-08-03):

<p align="center">
  <a href="README.md">Русский</a> | <b>English</b> | <a href="README.de.md">Deutsch</a>
</p>

# Manufacturing Files (Production)

This folder contains all materials necessary for self-fabrication of the printed circuit board, component sourcing, and assembly of the finished device.

## Directory Contents

* **[`gerber.zip`](/production/gerber.zip)** — ready-to-use archive with Gerber files and drill map. Fully ready to be uploaded to manufacturers' websites (JLCPCB, PCBWay, etc.).
* **[`breadboard-power-qcpd-bom.xlsx`](/production/breadboard-power-qcpd-bom.xlsx)** — Bill of Materials (BOM) with component specifications. 
  *(Note: the spreadsheet contains direct purchase links for electronics parts from the "Chip and Dip" store, though some links may become outdated over time).*
* **[`drawings/`](/production/drawings)** — complete set of engineering and design documentation (drawings, specifications) in **`.pdf`** format.

---

## Appearance of the Finished Device

Below are photographs of the assembled and tested physical prototype:

### 1. Assembled PCB View
<p align="center">
  Module PCB - top view
  &nbsp;&nbsp;&nbsp;&nbsp;
  Module PCB - bottom view
</p>

### 2. Laboratory Testing of the Prototype
<p align="center">
  Testing the assembled power module
</p>

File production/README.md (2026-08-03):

<p align="center">
  <b>Русский</b> | <a href="README.en.md">English</a> | <a href="README.de.md">Deutsch</a>
</p>

# Файлы для производства (Production)

Здесь содержатся все материалы, необходимые для самостоятельного изготовления печатной платы, закупки компонентов и сборки готового устройства.

## Содержимое директории

* **[`gerber.zip`](/production/gerber.zip)** — готовый архив с Gerber-файлами и картой сверловки. Полностью готов для загрузки на сайты изготовителей (JLCPCB, PCBWay и др.).
* **[`breadboard-power-qcpd-bom.xlsx`](/production/breadboard-power-qcpd-bom.xlsx)** — перечень элементов (Bill of Materials) со спецификациями компонентов. 
  *(Примечание: в таблице приведены прямые ссылки на покупку радиодеталей в магазине «Чип и Дип», однако со временем некоторые ссылки могут устаревать).*
* **[`drawings/`](/production/drawings)** — полный комплект конструкторской документации (чертежи, спецификации) в формате **`.pdf`**.

---

## Внешний вид готового устройства

Ниже представлены фотографии собранного и протестированного физического макета устройства:

### 1. Вид печатной платы в сборе
<p align="center">
  Печатная плата модуля - вид сверху
  &nbsp;&nbsp;&nbsp;&nbsp;
  Печатная плата модуля - вид снизу
</p>

### 2. Лабораторное тестирование макета
<p align="center">
  Тестирование собранного модуля питания
</p>

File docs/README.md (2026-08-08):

<p align="center">
  <b>Русский</b> | <a href="README.en.md">English</a> | <a href="README.de.md">Deutsch</a>
</p>

# Описание работы схемы модуля комбинированного питания

Данный документ содержит подробное техническое описание принципа работы электрической схемы «Модуля комбинированного питания для беспаечных макетных плат с поддержкой QC/PD».

<p align="center">
  Принципиальная схема устройства
</p>

## 1. Назначение и общая архитектура

Устройство предназначено для обеспечения стабильным многоканальным питанием беспаечных макетных плат в процессе прототипирования и отладки радиоэлектронной аппаратуры. Модуль преобразует входное напряжение от внешнего зарядного устройства или внешнего аккумулятора (Power Bank) с поддержкой протоколов быстрой зарядки в набор стабилизированных напряжений:
* **Канал быстрой зарядки (VBUS):** регулируемое напряжение 5 В, 9 В, 12 В, 15 В или 20 В (определяется запросом триггера).
* **Низковольтный канал питания логики:** фиксированное напряжение +3,3 В.
* **Канал отрицательного напряжения (двуполярное питание):** фиксированное напряжение -15 В.

---

## 2. Принцип работы функциональных узлов схемы

Электрическая схема устройства состоит из пяти основных взаимосвязанных блоков:

### 2.1. Входной узел USB Type-C
Работа модуля начинается с подачи внешнего питания на разъем **`X1`** (тип *TYPEC-304-ACP16*). 
* Контакты `A4/B9` и `B4/A9` объединены в общую входную силовую шину **`VBUS`**.
* Контакты `A1/B12` и `B1/A12` подключены к системной земле **`GND`**.
* Контакты конфигурации канала `CC1` и `CC2` выведены на триггер быстрой зарядки для ведения переговоров с источником питания.
* Светодиод **`VD2`** (с токоограничительным резистором `R10` номиналом 1 кОм) служит для визуальной индикации наличия входного напряжения на шине `VBUS`.

### 2.2. Узел согласования протоколов быстрой зарядки (QC/PD)
Ключевым элементом связи с адаптером является микросхема-триггер **`DD1`** типа **`CH224K`**. Она аппаратно поддерживает протоколы USB Power Delivery (PD3.0/2.0), Quick Charge (QC3.0/2.0) и другие.
* Сигнальные линии `DP` (D+) и `DM` (D-), а также линии конфигурации `CC1` и `CC2` подключены напрямую к соответствующим выводам `DD1`.
* Логика работы триггера определяется состоянием его конфигурационных входов `CFG1`, `CFG2` и `CFG3`. Входы подтянуты к внутренней шине питания `VDD` резисторами `R5`, `R6`, `R7` номиналом 10 кОм и управляются трехпозиционным DIP-переключателем **`SA2`** (*DS1040-03RN*).
* Замыканием соответствующих выводов переключателя `SA2` на землю (`GND`) пользователь принудительно задает уровень запрашиваемого напряжения (от 5 В до 20 В).

### 2.3. Узел линейного стабилизатора +3,3 В
Для надежного питания микроконтроллеров и цифровых датчиков используется мощный линейный стабилизатор с малым падением напряжения (LDO) **`DA2`** типа **`LD1086DT33TR`** (в корпусе TO-252).
* На вход `IN` стабилизатора подается напряжение с шины `VBUS`. Несмотря на то, что `VBUS` может возрастать до 20 В, микросхема `LD1086` безопасно выдерживает входное напряжение до 30 В.
* Для подавления высокочастотных помех и переходных процессов на входе и выходе стабилизатора установлены керамические конденсаторы **`C4`** (10 мкФ) и **`C5`** (10 мкФ).

### 2.4. Узел инвертирующего DC-DC преобразователя -15 В
Отрицательное напряжение генерируется импульсным понижающе-повышающим преобразователем на базе классического ШИМ-контроллера **`DA1`** типа **`MC34063AG-S08-R`** в инвертирующей конфигурации.
* **Принцип инверсии:** Когда внутренний ключевой транзистор микросхемы открыт, ток протекает через дроссель **`L1`** (220 мкГн), запасая энергию в его магнитном поле. Диод Шоттки **`VD1`** (*15MQ040N*) в этот момент закрыт. Когда транзистор закрывается, индуктивность стремится поддержать направление тока, ЭДС самоиндукции меняет полярность, диод `VD1` открывается, и в выходной конденсатор **`C3`** (47 мкФ) передается отрицательный заряд.
* **Защита по току:** Резистор **`R3`** (0,22 Ом), установленный между выводами `DRC/IPK` и входом питания, задает порог ограничения пикового тока дросселя, предотвращая выход преобразователя из строя при КЗ.
* **Обратная связь:** Выходное напряжение контролируется компаратором через делитель на резисторах **`R4`** (910 Ом), **`R5`** (750 Ом) и **`R1`** (10 кОм), подключенный к выводу обратной связи `CIIN` (Pin 5). Конденсатор **`C1`** (2,2 нФ) задает частоту переключения ШИМ-генератора ($\approx 97{,}5\text{ кГц}$).

### 2.5. Схема коммутации выходов и выходные разъемы
Распределение напряжений на левую и правую шины макетной платы осуществляется с помощью двух независимых ползунковых переключателей **`SA1`** и **`SA3`** (*MS-22D16G2-B*).
* Переключатели коммутируют физические выводы шин `3.3Vout`, `VBUS` и `-15out` на выходные штыревые разъемы **`X2`** и **`X3`** (тип *DS1021-2x5*).
* Разъемы имеют шаг 2,54 мм и расположены по краям платы таким образом, чтобы модуль вставлялся непосредственно в стандартные боковые шины питания беспаечной макетной платы.

---

## 3. Таблицы конфигурации переключателей

### 3.1. Выбор входного напряжения QC/PD (Переключатель `SA2`)

| `CFG1` | `CFG2` | `CFG3` | Выходное напряжение `VBUS` |
| :---: | :---: | :---: | :---: |
| 1 | — | — | **5 В** |
| 0 | 0 | 0 | **9 В** |
| 0 | 0 | 1 | **12 В** |
| 0 | 1 | 1 | **15 В** |
| 0 | 1 | 0 | **20 В** |

*Примечание: «1» означает разомкнутое состояние переключателя (высокий уровень за счет подтяжки к VDD), «0» — замкнут на GND.*

### 3.2. Коммутация шин питания макетной платы (Переключатели `SA1`, `SA3`)

| Положение `SA1` | Положение `SA3` | Напряжение на левой шине `X2` | Напряжение на правой шине `X3` |
| :---: | :---: | :---: | :---: |
| 1 | 1 | +3,3 В | -15 В |
| 0 | 1 | +3,3 В | +3,3 В |
| 0 | 0 | `VBUS` (от триггера) | `VBUS` (от триггера) |
| 1 | 0 | `VBUS` (от триггера) | -15 В |

---

## 4. Справочная техническая документация (Datasheets)

Для детального изучения работы примененных в схеме интегральных микросхем вы можете ознакомиться с оригинальной технической документацией производителей, расположенной в репозитории:

* 📄 **[`ch224k.pdf`](datasheets/ch224k.pdf)** — контроллер-триггер протоколов быстрой USB-зарядки (WCH).
* 📄 **[`ld1086.pdf`](datasheets/ld1086.pdf)** — мощный малошумящий линейный LDO-стабилизатор напряжения (STMicroelectronics).
* 📄 **[`mc34063a.pdf`](datasheets/mc34063a.pdf)** — универсальный импульсный ШИМ-контроллер DC-DC преобразователей (STMicroelectronics).

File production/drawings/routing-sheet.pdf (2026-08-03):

### ПРИЛОЖЕНИЕ 3

### Дубл

Взам.
Подп.

Комплект документов

### на технологический процесс сборки и монтажа

### «Модуль комбинированного питания для беспаечных макетных плат с поддержкой QC/PD»

ТЛ | Титульный лист

ПРИЛОЖЕНИЕ | ГОСТ 3.1123 – 84 Форма 7
Дубл
Взам
Подл | изм | лист | № докум | подпись | дата | изм | лист | № докум | подпись | дата
| | Листов 5 | Лист 1

Разраб
проверил
Т. Контр
ГТПП
Н. контр
К/М | Цех | Уч | РМ | Опер | Поз | Наименование ДСЕ или материала | Обозначение ДСЕ | ОПП | ЕВ | ЕН | КИ | Н.расх
Я | | | | | | | | | | Раз.п | Общ.п | Такт п.
| | 030 | | | 01 Плата | | ПК51.741424.001 | | шт. | 1 | | 1
| Резисторы
010,015,020,030 | 02 0.125 Вт 0603 13 кОм, 1% | R1 | шт. | 1 | 1
010,015,020,030 | 03 0.125 Вт 0603 10 кОм, 5% | R2 | шт. | 1 | 1
010,015,020,030 | 04 1 Вт 2512 0.3 Ом +1% | R3 | шт. | 1 | 1
010,015,020,030 | 05 0.125 Вт 0603 1.2 кОм, 1% | R4 | шт. | 1 | 1
010,015,020,030 | 06 0.125 Вт 0603 10 кОм, 5% | R5 | шт. | 1 | 1
010,015,020,030 | 07 0.125 Вт 0603 10 кОм, 5% | R6 | шт. | 1 | 1
010,015,020,030 | 08 0.125 Вт 0603 10 кОм, 5% | R7 | шт. | 1 | 1
010,015,020,030 | 09 0.125 Вт 0603 1 кОм, 5% | R8 | шт. | 1 | 1
010,015,020,030 | 10 0.125 Вт 0603 1 кОм, 5% | R9 | шт. | 1 | 1

Конденсаторы

КК | КОМПЛЕКТОВОЧНАЯ КАРТА

ПРИЛОЖЕНИЕ | ГОСТ 3.1123 – 84 Форма 7
Дубл
Взам
Подл | изм | лист | №докум | подпись | дата | изм | лист | №докум | подпись | дата
| | Листов 5 | Лист 2

Разраб
проверил
Т. Контр
ГТПП
Н. контр
К/М | Цех | Уч | РМ | Опер | Поз | Наименование ДСЕ или материала | Обозначение ДСЕ | ОПП | ЕВ | ЕН | КИ | Н.расх
Я | | | | | | | | | | Раз.п Общ.п | | Такт п.
| | 010,015,020,030 | | | 11 100пФ NP0 50В 5% 0603 | | C1 | | шт. | 1 | | 1
| | 010,015,020,030 | | | 12 1 мкФ X5R 50В 10% 0603 | | C2 | | шт. | 1 | | 1
| | 010,015,020,030 | | | 13 TECAP, 47мкФ, 20В, тип D, 10% | | C3 | | шт. | 1 | | 1
| | 010,015,020,030 | | | 14 TECAP, 10мкФ, 10В, тип A, 10% | | C4 | | шт. | 1 | | 1
| | 010,015,020,030 | | | 15 TECAP, 10мкФ, 10В, тип A, 10% | | C5 | | шт. | 1 | | 1
| Микросхемы
010,015,020,030 | 16 MC34063AG-S08-R | DA1 | шт. | 1 | 1
010,015,020,030 | 17 LD1086DT33TR | DA2 | шт. | 1 | 1
010,015,020,030 | 18 CH224K | DD1 | шт. | 1 | 1
| Индуктивности
010,015,020,030 | 19 B82464G4224M, 220мкГн | L1 | шт. | 1 | 1
КК | КОМПЛЕКТОВОЧНАЯ КАРТА

ПРИЛОЖЕНИЕ | ГОСТ 3.1123 – 84 Форма 7
Дубл
Взам
Подл | изм | лист | №докум | подпис
ь
дата | изм | лист | №докум | подпись | дата
| | Листов 5 | Лист 3

Разраб
проверил
Т. Контр
ГТПП
Н. контр
К/М | Цех | Уч | РМ | Опер | Поз | Наименование ДСЕ или материала | Обозначение ДСЕ | ОПП | ЕВ | ЕН | КИ | Н.расх
Я | | | | | | | | | | Раз.п | Общ.п | Такт п.
| | | | | Диоды
| | 010,015,020,030 | | | 20 15MQ040N, 40В 2.1А | | VD1 | | шт. | 1 | | 1
| Светодиоды
010,015,020,030 | 21 GNL-0603GC, 7-12мКд 120° 567нМ | HL1 | шт. | 1 | 1
| Коммутационные устройства
010,015,020,030 | 22 DPDT, SM190, 6P, 0.3А, 6В | SA1 | шт. | 1 | 1
010,015,020,030 | 23 DS1040-03RN | SA2 | шт. | 1 | 1
010,015,020,030 | 24 DPDT, SM190, 6P, 0.3А, 6В | SA3 | шт. | 1 | 1
| Разъёмы
010,015,020,030 | 25 TYPEC-304-ACP16 | X1 | шт. | 1 | 1
010,015,020,030 | 26 PLD-10 (DS1021-2x5) | X2 | шт. | 1 | 1
КК | КОМПЛЕКТОВОЧНАЯ КАРТА

ПРИЛОЖЕНИЕ | ГОСТ 3.1123 – 84 Форма 7
Дубл
Взам
Подл | изм | лист | №докум | подпись | дата | изм | лист | №докум | подпись | дата
| | Листов 5 | Лист 4

Разраб
проверил
Т. Контр
ГТПП
Н. контр
К/М | Цех | Уч | РМ | Опер | Поз | Наименование ДСЕ или материала | Обозначение ДСЕ | ОПП | ЕВ | ЕН | КИ | Н.расх
Я | | | | | | | | | | Раз.п Общ.п | | Такт п.
| | 010,015,020,030 | | | 27 PLD-10 (DS1021-2x5) | | X3 | | шт. | 1 | | 1
КК | КОМПЛЕКТОВОЧНАЯ КАРТА

ПРИЛОЖЕНИЕ - продолжение | ГОСТ 3.1123 – 84 Форма 7
Дубл
Взам
Подл | изм | лист | №докум | подпись | дата | изм | лист | №докум | подпись | дата
| | Листов 5 | Лист 5

Разраб
проверил
Т. контр
ГТПП
Н. контр
К/М | Цех | Уч | РМ | Опер | Поз | Наименование ДСЕ или материала | Обозначение ДСЕ | ОП П | ЕВ | ЕН | КИ | Н.расх
Я | | Вспомогательные материалы | | | | | | | | Раз.п | Общ.п | Такт п.
| | 010 | | | Спирто-нефрасовая смесь 1:1 | | | | кг | | | 0,0002
| | 025 | | | Спирто-нефрасовая смесь 1:1 | | | | кг | 1 | | 0,0007
| | 035 | | | Спирто-нефрасовая смесь 1:1 | | | | кг | 1 | | 0,005
| | 045 | | | Спирто-нефрасовая смесь 1:1 | | | | кг | 1 | | 0,02
| | 015 | | | Флюс ФКТ 40% | | ОСТ4ГО.033.200 | | кг | 1 | | 0,0026
| | 030 | | | Флюс ФКТ 40% | | ОСТ4ГО.033.200 | | кг | 1 | | 0,0053
| | 015 | | | Припой ПрвКР0,5 ПОС-61 | | ГОСТ21931-76 | | кг | 1 | | 0,0021
| | 030 | | | Припой ПрвКР0,5 ПОС-61 | | ГОСТ21931-76 | | кг | 1 | | 0,0042
| | 030 | | | Канифоль сосновая | | ГОСТ19113-84 | | кг | 1 | | 0,0031
| | 010 | | | Марля | | ГОСТ9412-77 | | пог. м | 1 | | 0,0003
| | 025 | | | Марля | | ГОСТ9412-77 | | пог. м | 1 | | 0,00074
| | 010 | | | Лак УР-231 | | | | кг | 1 | | 0,00012
| | 055 | | | Лак УР-231 | | | | кг | 1 | | 0,01
| | 025 | | | Краска МКЭ черная | | | | кг | 1 | | 0,0037
КК | | КОМПЛЕКТОВОЧНАЯ КАРТА

Дубл.
Взам.
Подп. | Изм | Лист | № докум. | Подпись | Дата | Изм | Лист | № докум. | Подпись | Дата
А | цех | Уч. | Рм | Опер. | Код, наименование операции | Обозначение | документа
Б | Код, наименование оборудования | см | Проф. | Р | УТ | КР | КОИД | ЕН | ОП | К шт. | Тп.з | Т шт.
К/М | Наименование детали, сб. единицы или материала | Обозначение, код | | | | | | ОПП | ЕВ | ЕН | КИ | Н.расх.

Исполнитель должен соблюдать общие требования к монтажу
| и сборке печатных узлов, блоков, субблоков РЭА в
| соответствии с инструкцией ВШО. 045.008И. ВШО. 045.008И
| Перед началом работы необходимо выполнить требования
| По исключению влияния статического электричества на полу-
| проводниковые приборы и интегралные микросхмы в соответствии Проволока мм 0,3
| СТПВШО. 025.220-2001, ОСТ11 073.063-84, и ВШО.045.008И. ОСТ11 073.063-84
| В процессе работы исполнители должны соблюдать требования СТПВШО. 005.220-2001
| и применять защитные средства, предусмотренные инструкциями ВШО.045.008И.
| по охране труда (ИОТ)
| ИОТ №119-89 – для лакировщика РЭА
| ИОТ №129-89 – для лудильшика горячим способом
| ИОТ №120-89 – для маркировшика РЭА
МК | Маршрутная карта

Дубл.
Взам.
Подп. | Изм | Лист | № докум. | Подпись | Дата | Изм | Лист | № докум. | Подпись | Дата
А | цех | Уч. | Рм | Опер. | Код, наименование операции | Обозначение | документа
Б | Код, наименование оборудования | см | Проф. | Р | УТ | КР | КОИД | ЕН | ОП | К шт. | Тп.з | Т шт.
К/М | Наименование детали, сб. единицы или материала | Обозначение, код | | | | | | ОПП | ЕВ | ЕН | КИ | Н.рас х.

ИОТ №130-85 – для монтажника радиоаппаратуры
ИОТ №156-88 – для контролера РЭА
ИОТ №158-89 – при хранении и обращении с диэтиленгликоль-уретаном (ДГУ), при приготовлении лака Р-231.
ИОТ №241-85 - для работающего с ЛВЖ и ГЖ.
В процессе работы отходы ЛВЖ и ГЖ сливать в специальную
тару ШМЧ.0835.00-00. После окончания работы отходы сдать
на пункт сбора в ОМТС.
005 Комплектование ВШ.30188.02433 Стол монтажниа
1. Проверить комплектность основных изделий и вспомога-ИОТ №130-85 ШНЧ.0242.0000 тельных материалов на соответствии комплектовочной карте.
МК | Маршрутная карта

Дубл.
Взам.
Подп. | Изм | Лист | № докум. | Подпись | Дата | Изм | Лист | № докум. | Подпись | Дата
А | цех | Уч. | Рм | Опер. | Код, наименование операции | Обозначение | документа
Б | Код, наименование оборудования | см | Проф. | Р | УТ | КР | КОИД | ЕН | ОП | К шт. | Тп.з | Т шт.
К/М | Наименование детали, сб. единицы или материала | Обозначение, код | | | | | | ОПП | ЕВ | ЕН | КИ | Н.рас
х.
005 2. Проверить внешний вид электрорадиодеталей на соответствие
ТУ и наличие клейма (документа), подтверждающего их годность.
3.Улажить ЭРЭ в тару Тара Ю6372-106
010 Подготовительная ВШ.30188.02433 Стол монтажника Проверить стойкость маркировочных знаков элементов ВШ.25273.00002 ШМЧ.0242.0000 к воздействию спирто-нефрасовой смеси 1:1 (количество ИОТ №130-85 Тара для ЛВЖ -выборочно 2 шт от каждой партии) и лакировать их при ВШ7878-4023 необходимости лаком УР-231 согласно технологической Пинцет ППМ 120 инструкии ВШ.25273.00002. АРПМ6.890.001.ТУ 015 Обслуживание паяемых поверхностей выводов ЭРЭ. ВШ.30188.02433 Тампон из марли
1. Флюсовать выводы элементов поз. 02-20 ВШ.25288.00000 Кисть КФК-8 погружением в ванну с флюсом ФКТ 40% ИОТ №129-89 ГОСТ 10597-87
МК | Маршрутная карта

Дубл.
Взам.
Подп. | Изм | Лист | № докум. | Подпись | Дата | Изм | Лист | № докум. | Подпись | Дата
А | цех | Уч. | Рм | Опер. | Код, наименование операции | Обозначение | документа
Б | Код, наименование оборудования | см | Проф. | Р | УТ | КР | КОИД | ЕН | ОП | К шт. | Тп.з | Т шт.
К/М | Наименование детали, сб. единицы или материала | Обозначение, код | | | | | | ОПП | ЕВ | ЕН | КИ | Н.рас
х.
Площадь платы 7,92 кв.дм
| 035 Элемент поз. 3 закрепить сначала клеем прокладку к плате поз.6 к эскизу.
| Крепление контровать краской МКЭ серой ОСТ4 ГО.054.180 ГОСТ 10313-78
| Сосуд с краской
БТК | 040 Контроль ВШ7850-009
| 045 Обезжирование Тампон из марли
| Обезжирить печатный узел в спиртово-нефрасовой смеси ИОТ №241-85 Кисть КМК-8
| 1:1 согласно ВШ.25000.00061 ГОСТ 10597-87
БТК | 050 Контроль Стол контролера
| 055 Лакирование ШНЧ.0242.0000
| Лакировать печатный узел лаком УР-231 и сушить Фото технология Установка
| согласно фото технологии ИОТ №119-89 ШН18.1980.00.00
| ИОТ № 158-89 ШН13.1950.00.00
| Стол лакировщика
МК | Маршрутная карта

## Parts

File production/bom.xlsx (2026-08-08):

Элементы | Обозначение | Типоразмеры | Наименование | Номиналы | Количество | Ссылка
Резисторы | R1 | R0603 |  | 13 кОм | 1 | https://www.chipdip.ru/product0/9000388849
 | R2, R5, R6, R7 | R0603 |  | 10 кОм | 4 | https://www.chipdip.ru/product/0.1w-0603-10-kom-5
 | R3 | R2512 |  | 0,3 Ом | 1 | https://www.chipdip.ru/product0/8003749926
 | R4 | R0603 |  | 1,2 кОм | 1 | https://www.chipdip.ru/product0/9000176517
 | R8, R9 | R0603 |  | 1 кОм | 2 | https://www.chipdip.ru/product/0.1w-0603-1-kom-5
Конденсаторы | C1 | C0603 |  | 100 пФ | 1 | https://www.chipdip.ru/product/grm1885c1h101j
 | C2 | C0603 |  | 1 мкФ | 1 | https://www.chipdip.ru/product/grm188r61h105kaald
 | C3 | CASE-D_7343 |  | 47 мкФ | 1 | https://www.chipdip.ru/product/tecap-47-mkf-20-v-tip-d-10
 | C4,C5 | CASE-A_3216 |  | 10 мкФ | 2 | https://www.chipdip.ru/product/tecap-10-mkf-10-v-tip-a-10
Микросхемы | DA1 | SOIC-8_L5.0-W4.0-P1.27-LS6.0-BL | MC34063AG-S08-R |  | 1 | https://www.chipdip.ru/product0/8014349442
 | DD1 | ESSOP-10_L4.9-W3.9-P1.0-LS6.0-TL-EP | CH224K |  | 1 | https://www.chipdip.ru/product0/8029704295
Стабилизатор | DA2 | TO-252-2_L6.5-W6.1-P4.58-LS10.0-TL | LD1086DT33TR |  | 1 | https://www.chipdip.ru/product/ld1086dt33tr-stm
Катушка | L1 | IND-SMD_L10.4-W10.2 | SPQ105-560M | 220 мкГн | 1 | https://www.chipdip.ru/product/b82464g4224m
Переключатели | SA1,SA3 | SW-TH_6P-L9.0-W3.5-P2.50-LS3.3 | MS-22D16G2-B COPY |  | 2 | https://www.chipdip.ru/product0/8008634629
 | SA2 | KEY-TH_DS1040-03RN | DS1040-03RN |  | 1 | https://www.chipdip.ru/product/ds1040-03rn
Диод шоттки | VD1 | SMA_L4.4-W2.6-LS5.2-RD | 15MQ040N |  | 1 | https://www.chipdip.ru/product/15mq040n-hottech
Светодиод | HL1 | LED0603_RED | LED-0603_R |  | 1 | https://www.chipdip.ru/product/gnl-0603gc
Разъёмы | X1 | USB-C-SMD_TYPE-C-16P-1 | TYPEC-304-ACP16 |  | 1 | https://www.chipdip.ru/product0/8015750283
 | X2,X3 | HDR-M-2.54_2X5 | HDR-M-2.54_2x5 |  | 2 | https://www.chipdip.ru/product/pld-10

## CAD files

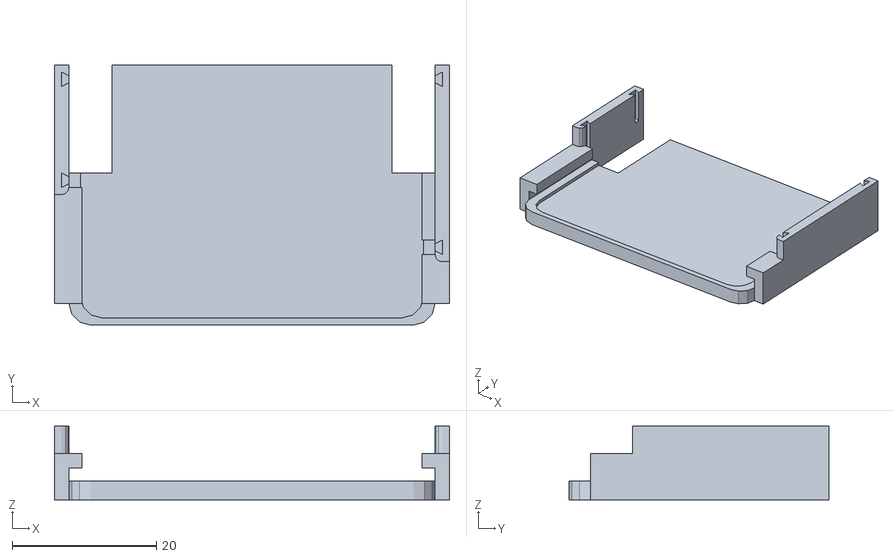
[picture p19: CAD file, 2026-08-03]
mechanical/enclosure/сase-bot.stl
54.8 x 36.1 x 10.2

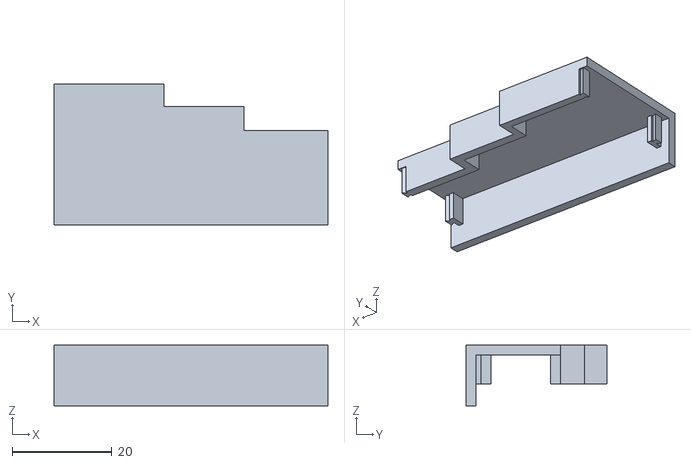
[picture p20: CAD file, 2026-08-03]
mechanical/enclosure/сase-top.stl
54.8 x 28.3 x 12.2

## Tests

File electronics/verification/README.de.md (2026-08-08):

<p align="center">
  <a href="README.md">Русский</a> | <a href="README.en.md">English</a> | <b>Deutsch</b>
</p>

# Elektrische Berechnung & Verifizierung des -15 V Inverters

Hier wird die detaillierte Berechnung der externen Beschaltung des Schaltregler-ICs **MC34063AG** im invertierenden Betrieb dargestellt, zusammen mit den Ergebnissen der praktischen Tests mit einem digitalen Oszilloskop.

Der invertierende Betrieb ist erforderlich, um eine stabile negative Spannung von $-15\text{ V}$ zu erzeugen. Diese wird für die symmetrische Versorgung analoger Baugruppen (Operationsverstärker, Komparatoren) auf einer lötfreien Steckplatine verwendet.

---

## 1. Schaltplan der Baugruppe

Der theoretische Schaltplan für den Anschluss des ICs im invertierenden Betrieb ist unten dargestellt:

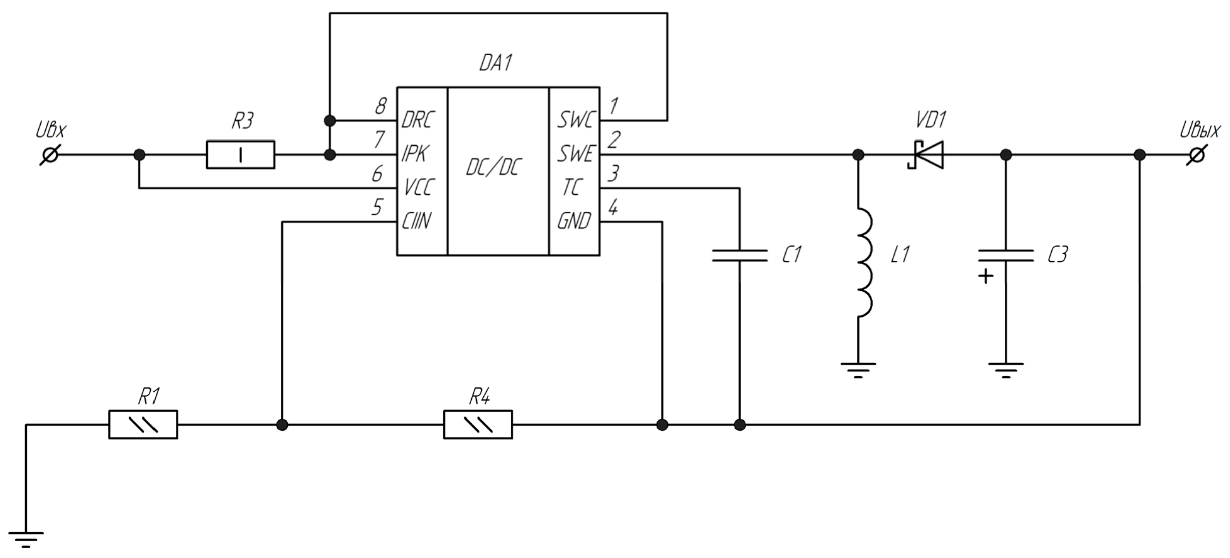
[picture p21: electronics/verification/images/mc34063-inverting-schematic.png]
Schaltplan der MC34063-Beschaltung


### Ausgangsparameter für die Berechnung:
* Maximale Eingangsspannung: $U_{\text{in(max)}} = 20\text{ V}$ (entspricht dem maximalen USB-Power-Delivery-Profil)
* Nominale Eingangsspannung: $U_{\text{in}} = 5\text{ V}$
* Erforderliche Ausgangsspannung: $U_{\text{out}} = -15\text{ V}$
* Maximaler Ausgangsstrom: $I_{\text{out}} = 100\text{ mA}$
* Zulässige Ausgangswelligkeit (Spannungsrippel): $U_{\text{ripple(peak-to-peak)}} = 10\text{ mV}$

---

## 2. Theoretische Berechnung der externen Bauteile

### 2.1. Bestimmung der Zeitintervalle und Frequenzwahl
Die Betriebsfrequenz des internen Oszillators wird durch die Kapazität des Kondensators $C_1$ (zwischen Pin `TC` und Masse) festgelegt. Um eine kompakte Bauweise des Geräts zu gewährleisten und die Abmessungen der Drossel zu minimieren, wird eine hohe Schaltfrequenz gewählt.

Anhand des Diagramms aus dem Datenblatt werden bei einer Kondensatorkapazität von $C_1 = 100\text{ pF}$ folgende Zeitintervalle gewählt:
* Einschaltzeit des Ausgangsschalters: $t_{\text{on}} = 4\ \mu\text{s}$
* Ausschaltzeit des Ausgangsschalters: $t_{\text{off}} = 1\ \mu\text{s}$

<p align="center">
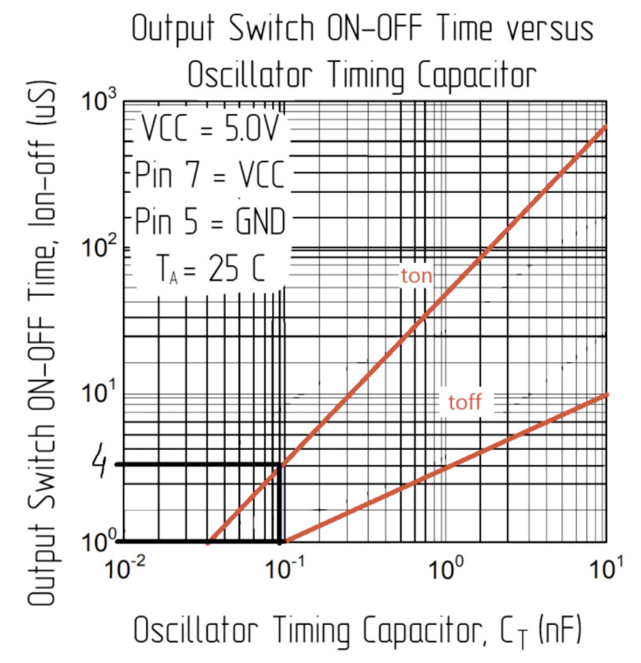
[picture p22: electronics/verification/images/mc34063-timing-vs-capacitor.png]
Frequenz-Kapazitäts-Diagramm
  
</p>
  
### 2.2. Berechnung des Sättigungsstroms der Drossel ($I_{\text{sat}}$)
Der Sättigungsstrom der Drossel $L_1$ wird nach folgender Formel berechnet:

$$I_{\text{sat}} = 2 \cdot I_{\text{out(max)}} \cdot \frac{t_{\text{on}} + t_{\text{off}}}{t_{\text{off}}}$$

Einsetzen der Werte:

$$I_{\text{sat}} = 2 \cdot 0{,}1 \cdot \frac{4 \cdot 10^{-6} + 1 \cdot 10^{-6}}{1 \cdot 10^{-6}} = 1\text{ A}$$

### 2.3. Berechnung der minimalen Induktivität der Drossel ($L_{\text{min}}$)
Die minimale Induktivität wird für den ungünstigsten Fall berechnet (bei maximaler Eingangsspannung):

$$L_{\text{min}} = \left( \frac{U_{\text{in(max)}} - U_{\text{out(sat)}}}{I_{\text{sat}}} \right) \cdot t_{\text{on(max)}}$$

Wobei $U_{\text{out(sat)}}$ die Sättigungsspannung des internen Ausgangstransistors des ICs bei einem Strom von $1\text{ A}$ ist. Laut Referenzdiagramm im Datenblatt beträgt dieser Wert $1{,}65\text{ V}$:

<p align="center">
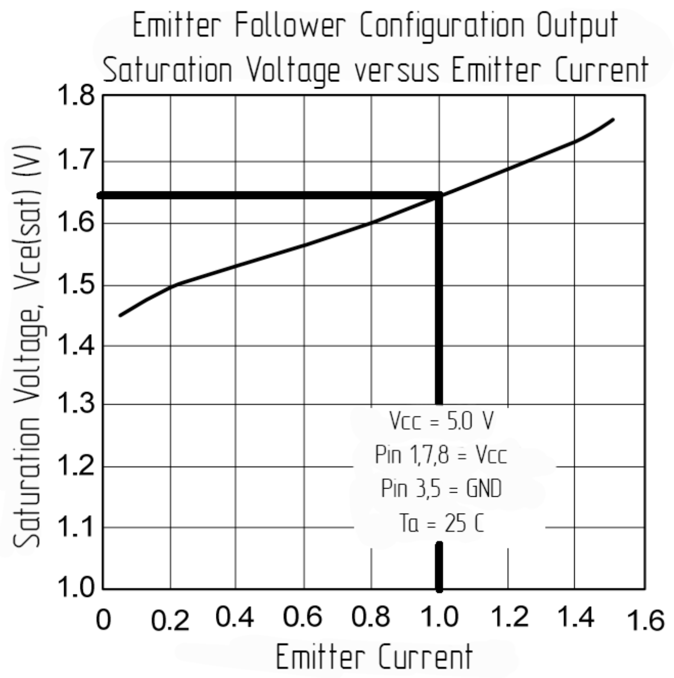
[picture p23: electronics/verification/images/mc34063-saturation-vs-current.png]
Sättigungsspannungs-Diagramm
  
</p>
  
Berechnung des Induktivitätswerts:

$$L_{\text{min}} = \left( \frac{20 - 1{,}65}{1} \right) \cdot 4 \cdot 10^{-6} \approx 73\ \mu\text{H}\ (73\ \mu\text{H})$$

*Bauteilauswahl:* Zur Erhöhung der Zuverlässigkeit, Reduzierung der Welligkeit und Gewährleistung des kontinuierlichen Betriebs wurde eine Standarddrossel mit einem Nennwert von **$220\ \mu\text{H}$** gewählt (Modell *SPQ105-560M* / *B82464G4224M*).

### 2.4. Berechnung des Strombegrenzungswiderstands ($R_3$)
Der Widerstand $R_3$ (verbunden mit Pin `IPK`) dient dem Überstromschutz des ICs:

$$R_3 = \frac{0{,}3}{I_{\text{sat}}} = \frac{0{,}3}{1} = 0{,}3\ \Omega\ (0{,}3\ \Omega)$$

*Auswahl des Nennwerts:* Es wurde ein niederohmiger Standardwiderstand mit **$0{,}22\ \Omega$** (oder $0{,}3\ \Omega$) gewählt.

### 2.5. Berechnung des Glättungskondensators ($C_3$)
Die Kapazität des Ausgangs-Glättungskondensators $C_3$ (in den Originalformeln der Abschlussarbeit als $C_1$ bezeichnet) wird wie folgt berechnet:

$$C_3 = \frac{I_{\text{out}} \cdot t_{\text{on}}}{U_{\text{ripple(peak-to-peak)}}} = \frac{0{,}1 \cdot 4 \cdot 10^{-6}}{10 \cdot 10^{-3}} = 40\ \mu\text{F}\ (40\ \mu\text{F})$$

*Bauteilauswahl:* Aus der Standardreihe E12 wurde ein Tantal-Kondensator mit einer Kapazität von **$47\ \mu\text{F}$** (Typ CASE-D) gewählt.

### 2.6. Theoretische Berechnung des Feedback-Teilers ($R_1$, $R_4$)
Zur Stabilisierung der Ausgangsspannung auf $-15\text{ V}$ wird der interne Komparator mit einer Referenzspannung von $1{,}25\text{ V}$ verwendet. Die theoretische Berechnung bei einem Teilerstrom von $I_{\text{div}} = 1\text{ mA}$ ergibt folgende Formeln:

$$R_1 = \frac{|U_{\text{out}}| - 1{,}25}{I_{\text{div}}} = \frac{15 - 1{,}25}{0{,}001} = 13750\ \Omega\ (13{,}75\text{ k}\Omega)$$

$$R_4 = \frac{1{,}25}{I_{\text{div}}} = \frac{1{,}25}{0{,}001} = 1250\ \Omega\ (1{,}25\text{ k}\Omega)$$

*Theoretische Auswahl aus der Reihe E24:* $R_1 = 13\text{ k}\Omega$, $R_4 = 1{,}2\text{ k}\Omega$.

---

## 3. Praktische Inbetriebnahme und Abgleich des Prototyps (Wichtig!)

Bei der Montage und dem ersten Einschalten des physischen Prototyps stellte sich heraus, dass die theoretischen Rückkopplungs- und Steuerkreiswerte aufgrund realer Spannungsabfälle an den Bauteilen und parasitärer Parameter angepasst werden müssen. 

### Änderungen in der finalen Version (v5):
1. **MC34063 Feedback-Teiler:** Um einen präzisen und stabilen Pegel von $-15\text{ V}$ auf der physischen Platine zu erhalten, wurde experimentell ein Teiler aus den Widerständen **$R_4 = 910\ \Omega$** und **$R_1 = 10\text{ k}\Omega$** (mit einem nachgeschalteten Trimmelement $R_5 = 750\ \Omega$) eingebaut. Dies kompensierte den Spannungsabfall an der Schottky-Gleichrichterdiode $VD_1$ und sicherte eine stabile Erzeugung des negativen Zweigs.
2. **CH224K Pull-up-Widerstände:** In den Konfigurationsschaltungen `CFG1–CFG3` des Schnelllade-Triggers wurden die Widerstandswerte von **$1\text{ k}\Omega$ auf $10\text{ k}\Omega$** geändert. Ein zu geringer Wert von $1\text{ k}\Omega$ hinderte das IC daran, die Logikpegel korrekt umzuschalten, um das gewünschte Spannungsprofil vom Netzteil anzufordern.

---

## 4. Ergebnisse der physischen Messungen (Verifizierung)

Zur Bestätigung der Stabilität der Schaltung wurde eine oszilloskopische Aufzeichnung der Signale an Schlüsselpunkten des Geräts durchgeführt.

### 4.1. Signalform am frequenzbestimmenden Kondensator $C_1$
Die tatsächliche Betriebsfrequenz des internen Generators betrug **$97{,}5\text{ kHz}$** (bei einem berechneten Maximum von $100\text{ kHz}$ für dieses IC). Die Spannungsform ist klassisch sägezahnförmig ohne Verzerrungen, was die Stabilität des internen Oszillators bestätigt.

<p align="center">
  Oszillogramm C1
</p>

### 4.2. Signalform an der Drossel $L_1$
Die Messung am Schaltknoten (Pin `SWE` / Anode der Diode `VD1`) bestätigt den Betrieb des Wandlers im berechneten Impulsmodus. Die Einschaltzeit beträgt $4\ \mu\text{s}$, die Ausschaltzeit $1\ \mu\text{s}$, was vollständig mit den berechneten Zeitparametern übereinstimmt. Die auftretenden hochfrequenten Schwingungen (Ringing) beim Schalten liegen innerhalb der zulässigen Grenzen für die ausgewählte Schottky-Diode $15MQ040N$.

<p align="center">
  Oszillogramm L1
</p>

---

## 5. Vergleich der berechneten und experimentellen Daten

| Parameter | Berechneter Wert | Tatsächlich (Prototyp) | Verifizierungsstatus |
| :--- | :---: | :---: | :--- |
| **Ausgangsspannung ($U_{\text{out}}$)** | -14,57 V | -15,02 V | **Bestanden** (Genauigkeit ≈ 3%) |
| **Betriebsfrequenz ($f$)** | 100 kHz (max) | 97,5 kHz | **Bestanden** (optimal für MC34063) |
| **Einschaltzeit ($t_{\text{on}}$)** | 4,0 µs | 4,0 µs | **Bestanden** (exakte Übereinstimmung) |
| **Ausschaltzeit ($t_{\text{off}}$)** | 1,0 µs | 1,0 µs | **Bestanden** (exakte Übereinstimmung) |
| **Welligkeitsamplitude (peak-to-peak)** | < 100 mV | ≈ 85 mV | **Bestanden** (mit Reserve für Steckplatinen) |

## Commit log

2026-08-02 feat: add 3.3V LDO stage and optimize CH224K configuration
    feat: add 3.3V LDO stage and optimize CH224K configuration
    - Added 3.3V LDO regulator stage (LD1086DT33TR) with filter capacitors
    - Added SW1 slide switch for power rail routing
    - Redesigned CH224K CFG pull-up network using 10k resistors
    - Replaced -15V circuit diode with BAT760-7 and adjusted timing capacitor
    - Completely redesigned PCB layout to accommodate new components and improve power routing
2026-08-02 feat: update schematic and PCB with SA1/SA3 switches and 2x5 headers
    - Replaced 2-pin connectors with 2x5 dual-row breadboard interface headers (X1, X2)
    - Replaced single switch with SA1 and SA3 DPDT switches for custom rail routing
    - Simplified -15V converter (DA1) by removing external MOSFET Q1
    - Replaced -15V rectifying diode with 15MQ040N
    - Renamed components to GOST standards (DA1, DD1, DA2, VD1, SA1-SA3)
    - Added detailed silkscreen truth table for switch configurations on the PCB
    - Added trace width and current calculation annotations to the schematic
2026-08-02 refactor: update SA1/SA3 switch model and fix schematic annotations
    - Replaced SA1 and SA3 slide switch symbols with MS-22D16G2-B
    - Highlighted critical "VBUS 1.5A 0.6mm" trace width annotation in red
    - Corrected DA2 regulator ground net connection to ensure proper netlist generation
2026-08-02 fix: correct feedback divider and pull-up resistor values for final PCB assembly
    fix: correct feedback divider and pull-up resistor values for final PCB assembly
    - Changed CH224K CFG pull-up resistors (R5, R6, R7) from 1k to 10k to restore logic switching
    - Corrected MC34063 feedback divider to R4=910 Ohm and R1=10k Ohm for stable -15V output
    - Finalized PCB routing and verified all trace connections after hardware prototyping
    - Updated silkscreen legends with confirmed switch logic table and configuration guides
2026-08-02 docs: add EasyEDA schematic and PCB screenshots
2026-08-03 docs: add schematic CDW and PDF drawings (v1)
2026-08-03 docs: update CDW and PDF drawings to final hardware revision
    Synchronized the official KOMPAS-3D schematic drawings with the physical board v5:
    - Replaced 2-pin connectors with final 10-pin header tables (X2, X3)
    - Redrew DIP switch SA2 as three independent SPST switches (SA2.1, SA2.2, SA2.3)
    - Replaced LED symbol VD2 with HL1 to comply with ESKD standards
    - Aligned all component values and designators with the actual working BOM
2026-08-03 docs: add final CDW and PDF manufacturing drawings
    Added the complete set of final production-ready drawings in both KOMPAS-3D (.cdw) and PDF formats:
    - Assembly drawing (assembly-drawing)
    - Assembly specification (assembly-specification)
    - Bill of Materials (bom)
    - General view drawing (general-view)
    - PCB layout drawing (pcb-drawing)
2026-08-03 docs: add bom.xlsx
    [bom.xlsx]
2026-08-03 style: rename bom to breadboard-power-qcpd-bom
    [breadboard-power-qcpd-bom.xlsx]
2026-08-03 feat: add 3D STEP model of the PCB assembly
2026-08-03 feat: add 3D models and assemblies for the enclosure
    Added the complete 3D mechanical CAD files for the module housing:
    - Enclosure lid (.m3d source and .stl for 3D printing)
    - Enclosure base/substrate (.m3d source and .stl for 3D printing)
    - Full mechanical assembly with the PCB (.a3d format)
    [крышка для диплома.stl, подложка для диплома.stl]
2026-08-03 docs(production): add Gerber ZIP archive for PCB fabrication
2026-08-03 docs(production): update Gerber ZIP archive to match final PCB
    Regenerated and updated the Gerber files for manufacturing:
    - Synced the track layout and copper layers with the final PCB v5
    - Ensured corrected MC34063 feedback and CH224K pull-up routing on the fabricated board
2026-08-03 style: rename enclosure files
    [breadboard-power-qcpd-сase-bot.stl, breadboard-power-qcpd-сase-top.stl]
2026-08-03 docs: update README.md
    Add language switch
2026-08-03 docs: create README.de.md
2026-08-03 docs: update README.de.md
    Add licence
2026-08-03 docs: update README.de.md
    Replaced the link to the license
2026-08-08 docs: replace bom due to recalculation
    [breadboard-power-qcpd-bom.xlsx]
2026-08-08 refactor: remove redundant project prefix from filenames
    Clean up repository file structure by removing the redundant
    `breadboard-power-qcpd-` prefix from filenames across all directories:
    - Simplify filenames in /production, /mechanical, and /electronics
    - Update relative file links in all README.md documents
    [bom.xlsx, сase-bot.stl, сase-top.stl]
2026-08-08 docs: remove LaTeX math from tables and fix relative asset links
    - Remove inline LaTeX math formulas from table cells across documentation
    README files (replaced with plain text like 5 V, +3.3 V, -15 V, —).
    This prevents GitHub's KaTeX renderer from wrapping formulas in
    overflow-x auto spans, fixing unwanted horizontal scrollbars.
    - Fix image and datasheet links by removing leading slashes from
    relative paths to ensure assets render correctly from any directory depth.
